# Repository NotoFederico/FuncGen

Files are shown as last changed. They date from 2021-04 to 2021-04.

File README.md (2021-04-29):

# WiFi Function and Arbitrary Waveforms Generator

---

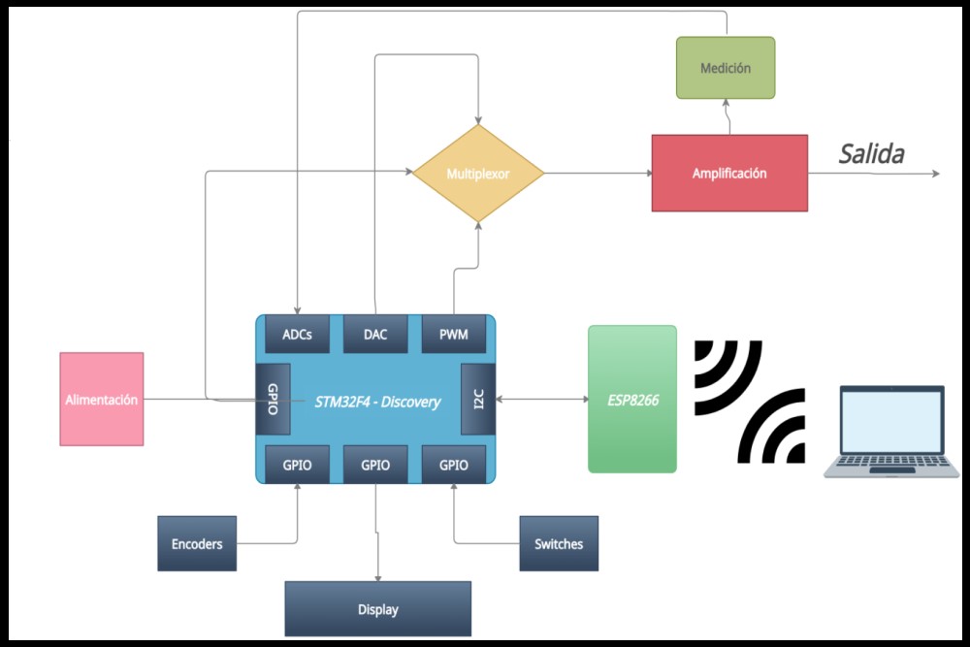
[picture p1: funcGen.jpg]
Project.Cover


---

### Download
| Latest release | Latest development build |
|---|---|
|  |  |

---

# Contents
- 1 - [Introduction](#1-introduction)
- 2 - [Paper Link](#3-paper-link)
- 3 - [Contributing](#4-contributing)
- 4 - [Licence](#5-licence)

---

# 1. Introduction

The present project aims to develop a function generator, which is exactly what its name implies: a test equipment that generates electrical signals in the form of waves that are used as stimuli for electronic measurements.

Most circuits require some type of input signal whose amplitude varies with time. The signal can be an alternating current signal (with peaks that oscillate above and below a reference) or it can vary over a range of direct current offset voltages, either positive or negative. It can be a sine wave or other analog function, a digital pulse, a binary pattern, or a purely arbitrary waveform.

The generator of signals, or functions, is the source of stimulus. Pair with a data acquisition instrument for a complete measurement solution. The two tools are connected to the input and output terminals of the device under test (DUT).

The signal generator can provide "ideal" waveforms, or it can add known and repeatable amounts and types of distortion (or errors) to the signal it delivers. This feature is one of the greatest virtues of the signal generator, as it is often impossible to create predictable distortion, exactly when and where it is needed, using only the circuit itself. The response of the device under test (DUT) in the presence of these distorted signals reveals its ability to handle voltages that fall outside the envelope of normal performance.

There are hundreds of different applications for this class of equipment, but placed in a context of electronic measurements, three categories can be divided: Verification: the designers of wireless equipment that develop new transmitting and receiving hardware must simulate baseband I&Q signals, with and without deficiencies, to verify compliance with proprietary wireless standards using arbitrary low-distortion functions.

Characterization: Newly developed digital-to-analog converters (DACs) and analog-to-digital converters (ADCs) must be thoroughly tested for their limits for linearity and distortion. Analog and digital signals are applied in phase to bring the speeds of these devices up to 1Gbps. Stress or margin test: engineers working with serial data flow architectures (commonly used in digital communication buses) need to stress their devices with deficiencies, particularly fluctuations and synchronization violations

In the project in question, known signals can be generated: such as sine, semi-diverse, square, rectangular, triangular, sawtooth and white noise and arbitrary signals, which are those signals of complex origin that do not follow a regular mathematical expression and that can be generated by the user using specialized software and subsequently sent over WiFi, thanks to a dedicated website. These signals can be chosen through a menu and their parameters, such as duty, offset and amplitude, are modifiable and will be monitored in real time on a display.

---

# 2. Paper Link

[Paper (Spanish)](https://github.com/NotoFederico/FuncGen/blob/main/FuncGen_STM32DISCO/Informe.pdf)

---

# 3. Contributing

FuncGen uses the [gitflow workflow](https://www.atlassian.com/git/tutorials/comparing-workflows#gitflow-workflow). If you are implementing a new feature or logic from the original game, please branch off and perform pull requests to ```develop```. If you are fixing a bug for the next release, please branch off and perform pull requests to the correct release branch. ```master``` only contains tagged releases, you should never branch off this.

---

# 4. Licence

FuncGen is licensed under the GNU General Public License version 3.

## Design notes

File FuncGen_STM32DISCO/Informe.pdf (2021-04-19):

## UNIVERSIDAD NACIONAL DE LA MATANZA

## Departamento de Ingeniería e Investigaciones Tecnológicas

## Ingeniería en Electrónica

# Técnicas digitales III

# Generador de funciones y ondas arbitrarias

Integrantes: | Federico A. Noto
Profesores: | Lic. Carlos Maidana
| Ing. Guillermo Buranits
| Ing. Lucas M. Guerrero
| Ing. Mauro Cipollone

2021

# ÍNDICE

UNLaM | Ingeniería Electrónica | Técnicas Digitales III
Noto Federico Antonio | 3

# 1 Descripción general

El presente proyecto tiene por objetivo desarrollar un generador de funciones, que es exactamente lo que su nombre implica: un equipo de testeo que genera señales eléctricas en forma de ondas que se utilizan como estímulo para mediciones electrónicas.

La mayoría de los circuitos requieren algún tipo de señal de entrada cuya amplitud varía con el tiempo. La señal puede ser una señal de corriente alterna (con picos que oscilan por encima y por debajo de una referencia) o puede variar en un rango de tensiones de offset de corriente continua, ya sea positivo o negativo. Puede ser una onda sinusoidal u otra función analógica, un pulso digital, un patrón binario o una forma de onda puramente arbitraria.

El generador de señales, o de funciones, es la fuente de estímulo. Se empareja con un instrumento de adquisición de datos para obtener una solución de medición completa. Las dos herramientas se conectan en los terminales de entrada y salida del dispositivo bajo prueba (DUT).

El generador de señales puede proporcionar formas de onda "ideales" o puede agregar cantidades conocidas y repetibles y tipos de distorsión (o errores) a la señal que entrega. Esta característica es una de las mayores virtudes del generador de señales, ya que a menudo es imposible crear una distorsión predecible, exactamente cuando y donde es necesario, utilizando solo el circuito en sí. La respuesta del dispositivo bajo prueba (DUT) en la presencia de estas señales distorsionadas revela su capacidad para manejar tensiones que caen fuera de la envolvente del rendimiento normal.

Existen cientos de aplicaciones diferentes para esta clase de equipos, pero colocado en un contexto de mediciones electrónicas, se pueden divisar tres categorías:

Verificación: los diseñadores de equipos inalámbricos que desarrollan nuevo hardware de transmisión y recepción deben simular señales I&Q de banda base, con y sin deficiencias, para verificar la conformidad con los estándares inalámbricos patentados y para ello se usan funciones arbitrarias de baja distorsión.

Caracterización: los convertidores digital a analógico (DAC) y los convertidores analógico a digital (ADC) recientemente desarrollados deben probarse exhaustivamente para determinar sus límites de linealidad y distorsión. Se aplican señales analógicas y digitales en fase para llevar las velocidades de estos dispositivos hasta 1Gbps.

Test de estrés o margen: los ingenieros que trabajan con arquitecturas de flujo de datos en serie (comúnmente utilizadas en buses de comunicaciones digitales) necesitan estresar sus dispositivos con deficiencias, particularmente fluctuaciones y violaciones de sincronización

En el proyecto en cuestión, se podrán generar señales conocidas: como seno, semiverseno, cuadrada, rectangular, triangular, diente de sierra y ruido blanco y señales arbitrarias, que son aquellas señales de origen complejo que no siguen una expresión matemática regular y que podrán ser generadas por el usuario mediante un software especializado y posteriormente enviadas a través de WiFi, gracias a un sitio web dedicado. Dichas señales podrán ser elegidas a través de un menú y sus parámetros, tales como duty, offset y amplitud, son modificables y serán monitoreados en tiempo real en un display.

# 2 Introducción teórica

## 2.1 Forma de onda

El término "onda" se puede definir como un patrón de valores cuantitativos variables que se repite durante algún intervalo de tiempo. Las ondas son comunes en la naturaleza: ondas sonoras, ondas cerebrales, ondas oceánicas, ondas de luz, ondas de tensión y muchas más. Todos son fenómenos que se repiten periódicamente. Los generadores de señales generalmente se preocupan por producir ondas eléctricas (típicamente de voltaje) que se repiten de manera controlable.

Cada repetición completa de una onda se conoce como un "ciclo". Una forma de onda es una representación gráfica de la actividad de la onda: su variación en el tiempo. Una forma de onda de tensión es un gráfico cartesiano clásico con tiempo en el eje horizontal y tensión en el eje vertical.

## 2.1.1 Amplitud

Una medida de la “fuerza” de la tensión de la forma de onda. La amplitud cambia constantemente en una señal de corriente alterna. Los generadores de señales le permiten establecer un rango de tensión, por ejemplo, —5V a +5V. Esto producirá una señal que fluctuará entre los dos valores de tensión, y la tasa de cambio dependerá tanto de la forma de onda como de la frecuencia.

## 2.1.2 Frecuencia

La velocidad a la que ocurren los ciclos completos de formas de onda. La frecuencia se mide en Hertz (Hz), antes conocida como ciclos por segundo. La frecuencia está inversamente relacionada con el período de la forma de onda, que es una medida de la distancia entre dos picos similares en ondas adyacentes. Las frecuencias más altas tienen períodos más cortos y viceversa.

## 2.1.3 Fase

En teoría, es la ubicación de un ciclo de una forma de onda en relación con un punto de 0 grados. En la práctica, la fase es la ubicación temporal de un ciclo en relación con una forma de onda de referencia o de un punto en el tiempo.

## 2.1.4 Tiempo de subida y de bajada

Más conocido como rise time y fall time respectivamente. Son medidas del tiempo que tarda el flanco de la señal en realizar una transición de un estado a otro. En los circuitos digitales modernos, estos valores suelen estar en el rango de nanosegundos o menor.

Los tiempos de subida y bajada se miden entre los puntos del 10% y el 90% de los niveles de tensión estático antes y después de la transición (a veces se utilizan puntos del 20% y del 80% como alternativas).

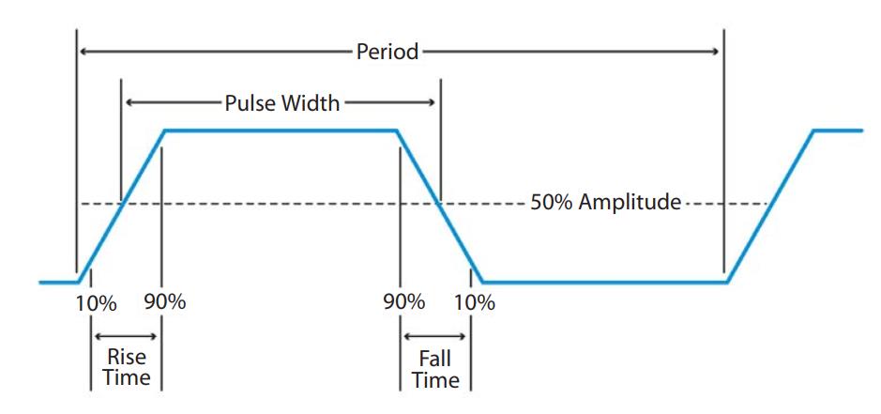
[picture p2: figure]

Figura 1 - <Características básicas de un pulso>

## 2.1.5 Ancho de pulso

El ancho de pulso es el tiempo que transcurre entre los flancos inicial y final de un pulso. Para tener en cuenta que el término "inicial" se aplica a los flancos positivos o negativos, al igual que el término "final". En otras palabras, estos términos denotan el orden en que ocurren los eventos durante un ciclo dado. La polaridad de un pulso no afecta su estado como flanco inicial o final.

Otro término, "ciclo de trabajo" (duty cycle), se usa para describir los intervalos de tiempo alto y bajo (encendido / apagado) de un pulso. Por ejemplo, un actuador que descansa 3 segundos luego de 1 segundo de actividad representa un duty cycle del 25% en un periodo de 4 segundos.

## 2.1.6 Offset

No siempre las señales tienen sus variaciones de amplitud centradas en una referencia de tierra (0V). La tensión de "offset" es la tensión entre la tierra del circuito y el centro de la amplitud de la señal. La tensión de offset expresa la componente de corriente continua de una señal que contiene valores tanto de corriente alterna como de corriente continua.

Figura 2 - <Tensión de offset sobre una señal alterna>

## 2.2 Conversor digital a analógico (DAC)

Un convertidor digital a analógico (DAC) es un dispositivo que convierte un código digital en una señal analógica. Los convertidores digitales a analógico son la interfaz entre el mundo digital abstracto y la vida real.

En la siguiente imagen puede apreciarse que N palabras digitales de n bits son aplicadas a la entrada del DAC, que luego se convierten en una señal analógica a la frecuencia de muestreo (Fs) aplicada al clock del DAC.

Figura 3 - <Características básicas del DAC>

## 2.2.1 Profundidad de memoria (longitud de registro)

La profundidad de la memoria, o la longitud del registro, está íntimamente ligada con la frecuencia del clock. La profundidad de la memoria determina el número máximo de muestras que se pueden almacenar. Cada punto de muestra de forma de onda ocupa una ubicación de memoria. Cada ubicación equivale al valor de un intervalo de muestra de tiempo a la frecuencia del clock actual. Si el clock funciona a 100 MHz, por ejemplo, las muestras almacenadas están separadas por 10 ns.

## 2.2.2 Frecuencia de muestreo

La frecuencia de muestreo, generalmente especificada en términos de MS/s o GS/s, denota el clock máximo o la frecuencia de muestreo a la que puede funcionar el instrumento. La frecuencia de muestreo afecta la frecuencia y fidelidad de la señal de salida. El teorema de muestreo de Nyquist establece que la frecuencia de muestre, debe ser más del doble que la componente de frecuencia espectral más alta de la señal generada, para garantizar una reproducción precisa de la señal. Para generar una señal de onda sinusoidal de 1 MHz, por ejemplo, es necesario producir puntos de muestra a una frecuencia de más de 2 MS/s.

## 2.2.3 Resolución Vertical

La resolución vertical se refiere al tamaño de la palabra binaria en bits del DAC del instrumento. Más bits equivalen a una resolución más alta. La resolución vertical del DAC define la precisión de amplitud

(tensión) y la distorsión de la forma de onda reproducida. Un DAC con resolución inadecuada contribuye a errores de cuantificación, provocando una generación de forma de onda imperfecta.

## 2.2.4 Resolución Horizontal

La resolución horizontal expresa el incremento de tiempo más pequeño que se puede utilizar para crear formas de onda. Normalmente, esta cifra es simplemente el resultado del cálculo:

T = 1 / F donde T es la resolución de tiempo en segundos y F es la frecuencia de muestreo.

## 2.3 Modulación por ancho de pulso (PWM)

La modulación por ancho de pulsos (PWM, de sus siglas en inglés) de una señal o fuente de energía es una técnica en la que se modifica el ciclo útil de una señal periódica (pudiendo ser una senoidal o una cuadrada), para transmitir información a través de un canal de comunicaciones o para controlar la cantidad de energía que se envía a una carga.

El ciclo de trabajo de una señal periódica es el ancho relativo de su parte positiva en relación con el período. Expresado matemáticamente:

Ciclo útil =

Tiempo de la señal en esta alto Tiempo total del período

En la actualidad existen muchos circuitos integrados en los que se implementa la modulación PWM, además de otros muy particulares para lograr circuitos funcionales que puedan controlar fuentes conmutadas, controles de motores, controles de elementos termoeléctricos, etc.

# 3 Descripción técnica del proyecto

## 3.1 Hardware

Las prestaciones del equipo son las siguientes:

- Formas de onda: senoidal, semiverseno, diente de sierra, triangular, cuadrada, rectangular, ruido blanco y ondas arbitrarias.
- Para la forma de onda rectangular se puede elegir un ciclo de trabajo del 1% al 99% con una resolución de 8 bits.
- Rango de frecuencia: 1Hz a 20kHz
- Resolución de frecuencia: +/- 1Hz para frecuencias bajas; +/- 100Hz para frecuencias altas
- Amplitud: 0Vpp a 20Vpp
- Resolución de amplitud: 200mV
- Offset: +/- 5V
- Resolución del offset: 20mV
- Cantidad de muestras: 4000

## 3.1.1 Diagrama en bloques

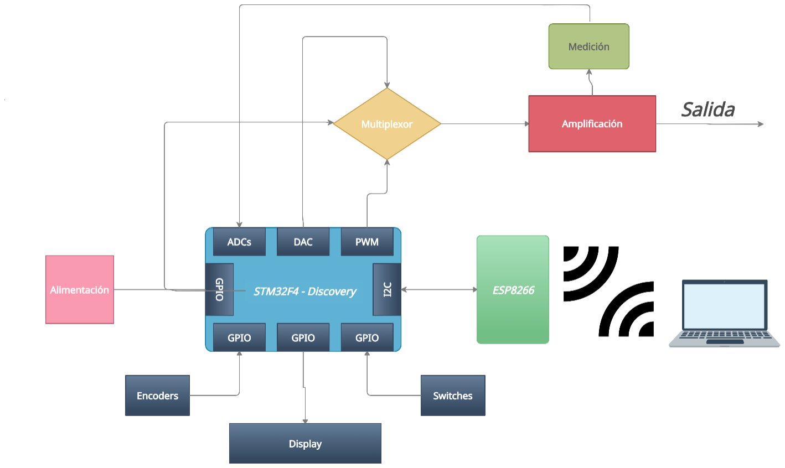
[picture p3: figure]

Figura 4 - <Diagrama en bloques del proyecto>

A partir de una fuente de 24V se alimenta al equipo, donde se derivan los niveles de tensión necesarios para cada bloque. Los diferentes periféricos de los que se hablará a continuación forman parte del kit de desarrollo STM32F4 – Discovery.

Dentro de los GPIO (perifericos generales de entrada/salida) de entrada, nos encontramos con encoders rotativos y switches que nos permiten interactuar con un simple menú que nos permiten elegir distintas pantallas, elegir formas de onda y seleccionar valores de magnitudes unidad por unidad. El menú puede visualizarse en un display de 20x4 caracteres (periferico general de salida).

La forma de onda elegida puede ser generada a través del DAC (conversor digital a analógico) para formas de onda clásicas como seno, semiverseno, triangular, diente de sierra y ruido blanco y otras especiales como las ondas arbitrarias. Luego con el PWM puede generarse formas de onda tal como cuadrada y rectangular. Tanto la salida del DAC como PWM están conectadas a un multiplexor que selecciona solo una sola señal, dicha selección está controlada por un GPIO proveniente del microcontrolador. Posteriormente, la señal elegida es amplificada y acondicionada para ser leída por un ADC, dichas magnitudes pueden ser consultadas en cualquier momento en el display.

El bloque perteneciente al ESP8266, levanta un servidor que permite la gestión de ondas arbitrarias a través de WiFi y se comunica con el microcontrolador utilizando el protocolo I2C. Las ondas arbitrarias deberán ser generadas previamente con un software especializado para dicha actividad y luego cargadas al sitio web en LAN para que el usuario gestione las formas de onda cargadas en el servidor.

## 3.1.2 Esquemático

3.1.2.1 Bornera de fuente de alimentación

Una simple bornera de dos pines alimenta a todo el circuito con una fuente de 24V.

3.1.2.2 Alimentación principal +/-12V

La fuente de 24V es dividida en +/-12V con una tierra virtual.

Figura 5 - <Esquemático de alimentación +/-12V>

3.1.2.3 Alimentación principal +5V y 3.3V

Las tensiones de alimentación de +5 y +3.3V se logran con circuitos integrados de reguladores, LM7805 y LM7833 respectivamente. La tensión de entrada en cada caso es de +12V y se colocan capacitores tanto en la entrada como en la salida tal como especifica la hoja de datos. En la entrada un capacitor electrolítico de 0.22uF con referencia a GND por si el filtro de fuente se encuentra lejos del regulador y en la salida un capacitor cerámico de 100nF con referencia a GND para mayor estabilidad.

3.1.2.4 STM32F4-Discovery Kit

Se utiliza a la placa de desarrollo como eje central de este proyecto. Se encarga de generar las formas de onda, aplica el algoritmo matemático necesario para la obtención de cada señal y también el algoritmo para determinar la cantidad de muestras y la frecuencia de muestreo, tanto para las formas de onda que correspondan al DAC o al PWM. También es el responsable de enviar las cadenas de caracteres que se desean imprimir en el display (enable (E), reset (RS), DB4-DB7), de colocar el valor lógico correspondiente en ChSelect para conmutar la salida del multiplexor, de interpretar la posición de los dos encoders (CLKx, DTx y SWx), de atender las interrupciones de hardware de los dos pulsadores (SW3 y SW4), de recibir la información correspondiente de las ondas arbitrarias mediante el protocolo I2C (SDA y SCL) que actua como esclavo y de interpretar los valores de tensión recibidos a las entradas de los tres ADCs: tensión de salida amplificada de la señal (AmpDac), tensión de salida del offset (OffsetDac) y signo del offset (PolarityDac). Es alimentada con +5V provenientes de una conexión USB.

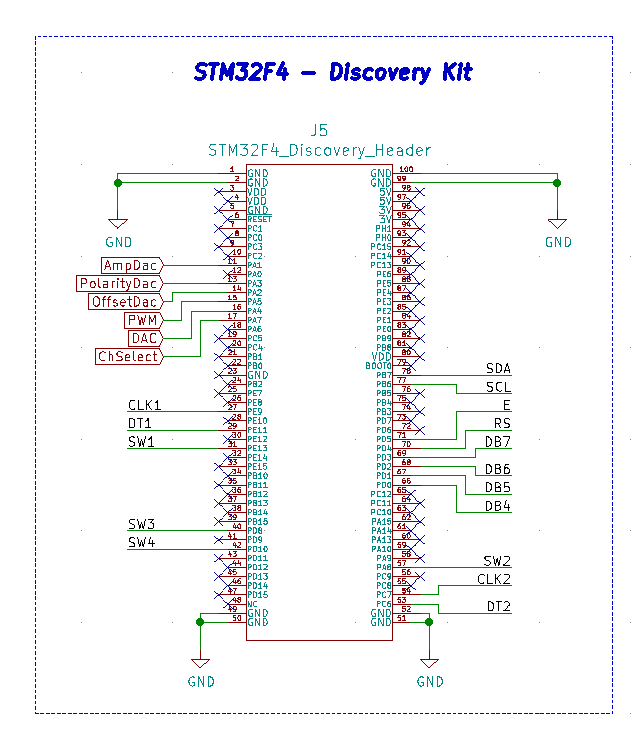
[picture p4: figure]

Figura 6 - <Esquemático del kit STM32F4 - Discovery>

3.1.2.5 ESP8266 – NODEMCU – 1.0

El ESP8266 NODEMCU es un kit de desarrollo que ofrece una solución completa con conectividad WiFi, lo que le permite alojar la aplicación o servir como puente entre internet y un microcontrolador.

Se eligió este kit por su practicidad en cuanto aspectos de alimentación vía puerto micro USB, facilidad de programación, tamaño de memoria y la posibilidad de expansión del proyecto, dado que hay muchos periféricos aún disponibles.

Esta versión en particular cuenta con 30 pines disponibles para el usuario de los cuales nos son de interés los pines de +3.3V de alimentación y los de comunicación I2C (SCL y SDA), con los cuales el ESP8266 establece una comunicación como maestro, con el microcontrolador. El fin de este dispositivo en el proyecto es levantar un servidor (WebSocket) que aloja una página web (HTML, CSS, JS) en la red de área local (utilizando DHCP) para listar, subir, enviar (I2C) y borrar archivos que almacenen conjuntos de muestras de formas de ondas arbitrarias (.csv).

3.1.2.6 Display 2004A

Es un display de 20x4 caracteres, que se alimenta con +5V y lleva un capacitor de 100nF como protección contra sobretensiones. El ánodo se conecta a +5V y el cátodo a GND (para encender el display). Luego el brillo de los caracteres se regula con un trimpot de 10k conectado al pin VO del display, como recomienda la hoja de datos del fabricante. Se conecta de tal manera para que funcione como divisor resistivo, con la alimentación en los extremos y el punto medio conectado a VO. Luego los pines de información solo se utilizan de DB4-DB7 y los de control como Reset (RS), Enable (E) y Read/Write(RW) a GND para realizar escrituras.

La función del display en el proyecto es mostrar las diferentes “pantallas” del menú, para una fácil interacción entre el usuario y el equipo. Se eligió por su practicidad, bajo precio y experiencia previa con esta clase de display.

3.1.2.7 Switches

Dos simples switches conectados entre GND y los GPIO del microcontrolador, funcionan como interrupciones externas de hardware para desplazarse por las distintas pantallas del menú, de arriba hacia abajo y viceversa.

3.1.2.8 Encoders

Dos encoders rotativos KY-040 se utilizan para que el usuario interactúe en cada “pantalla” del menú, permitiendo seleccionar unidades y números referentes a magnitudes tales como frecuencia y duty cycle y seleccionar la forma de onda de salida. Uno de los encoders se encarga siempre de los desplazamientos en el eje horizontal y el otro de los encoders se encarga siempre de los desplazamientos en el eje vertical.

Cada encoder tiene 5 pines, DT, SW, CLK, +5V y GND. Los primeros tres son conectados al microcontrolador principal y controlados por un timer en modo encoder y los otros dos pines a alimentación. Se eligieron pensando en una experiencia de usuario diferente a utilizar un teclado matricial y porque el microcontrolador ofrece un modo de configuración idóneo para este tipo de periférico.

3.1.2.9 Selección de señal
En este apartado se logra que con un estado o alto o bajo proveniente de ChSelect pueda elegirse que la señal del DAC o del PWM pase a una instancia de amplificación. Para ello se utilizó un integrado multiplexor/demultiplexor, el CD4051. Este posee, ocho entradas, una salida, tres pines de control y un pin de habilitación. Este integrado es alimentado con +5V y lleva un capacitor de 100nF como protección contra sobretensiones. De las ocho entradas utilizamos solo dos, cableadas a DAC y PWM, X0 y X1 respectivamente. Con solo el pin de control A se logra controlar la selección entre ambas entradas (X0 y X1), mientras que los pines B, C y INHIBIT permanecen conectados a GND (ver tabla de verdad).

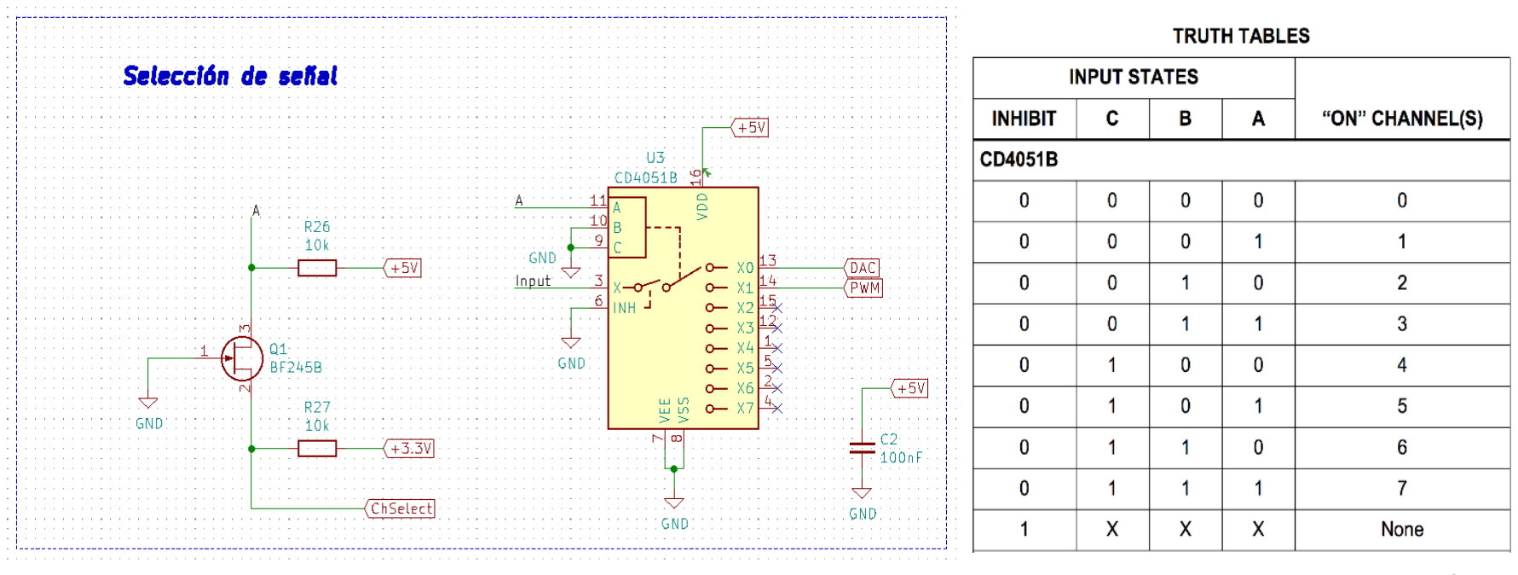
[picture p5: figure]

Figura 7 - <Tabla de verdad de selección de canal del CD4051>

Según la hoja de datos, con una alimentación de +5V, se necesita una tensión de hasta 1.5V para que el integrado interprete un “0” lógico y más de 3.5V para un “1” lógico. Dado que la tensión de salida de los pines del microcontrolador principal excursionan entre 0V y 3.3V necesitamos shiftear o adaptar los niveles de tensión. Como solución a este problema se implementó un circuito level shifter con un JFET BF245B. El gate del mismo está conectado a GND, el source a ChSelect y el drain a la salida del pin del control A y a +5V a través de un resistor de 10kΩ. Cuando ChSelect es 0V la tensión entre gate y source es también 0V, por lo tanto, la VGS del transistor es 0V, entonces no fluye corriente a través del drain y la tensión en A, es de alrededor de 0V. Si ahora en ChSelect se aplica una tensión de 3.3V, la VGS será de 3.3V y logramos que la tensión en el drain y por lo tanto en A, sea de 5V.

Figura 8 - <Esquemático de selección de señal>

3.1.2.10 Amplificación y acondicionamiento de la señal de amplificación

Posterior a la selección de la señal, la etapa que siguiente es la de amplificación. Primeramente, se desacopla de su componente de continua, dado que la señal que genera el DAC tiene una tensión mínima de 0V y una máxima de 2.92V (limitada para no deformar la forma de onda), lo que implicaría que ya tiene un offset de 1.46V aproximadamente. De esta manera, montamos el centro de la señal sobre 0V. Se utilizan dos capacitores en paralelo de 133uF en total (100uF + 33uF). Realizamos esta configuración con valores experimentales ya que en la práctica se observó que la señal de salida estaba derivándose para bajas frecuencias (< 20Hz), dado que el capacitor de desacople seguido por un amplificador inversor toma la topología de un amplificador derivador. Según una simulación en LTSpice, se comprobó que para valores de R10 = 33kΩ y R7 = 5.6kΩ, a pesar de obtener una ganancia cercana a la deseada (G = -R10/R7) el efecto del derivador actuaba para frecuencias menores a 20 Hz.

Figura 9 - <Respuesta en frecuencia con R10 = 33kΩ y R7 = 5.6kΩ >

Del gráfico observamos que f−3db = ~3 Hz y f0db = 36mHz

Como solución se elevaron los valores de R10 y R7 para que el efecto de derivación no ocurra en el rango de frecuencias de este generador. Los nuevos valores de resistores propuestos son R10 = 680kΩ y R7 = 100kΩ.

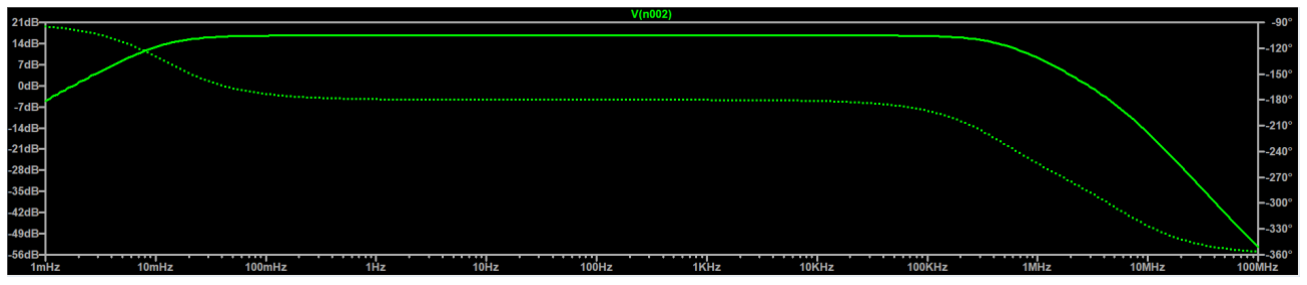
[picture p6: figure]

Figura 10 - <Respuesta en frecuencia con R10 = 680kΩ y R7 = 100kΩ.>

Del gráfico observamos que f−3db = ~160 mHz y f0db = 1. 76mHz

La ganancia es constante entre 1Hz y 20kHz. El efecto del derivador ocurre entre 1.76mHz y 160mHz. También ocurre que la señal es integrada para señales a partir de 1MHz.

Una vez desacoplada la señal la señal es amplificada con un amplificador operacional (TL072, doble AOP de propósito general) en configuración inversora y alimentado con ±12V, que se rige por la siguiente ecuación:

Vi ∗

680kΩ
100kΩ

= Vo → Vi ∗ 6.8 = 2.92V ∗ 6.8 = 19.85Vpp

Cumpliendo con el requerimiento de entregar alrededor de 20Vpp. Ahora bien, lo que hemos conseguido hasta aquí es que la señal alcance su valor máximo, aunque sin regulación. Entonces utilizamos un potenciómetro de 100kΩ para atenuar la señal hasta un valor mínimo de 19.85Vpp ∗

1Ω
100kΩ

= 0.19mVpp y un máximo de 20Vpp. Finalmente se emplea el otro AOP de la pastilla como buffer y entregar una señal con muy baja impedancia de salida.

Un detalle no menor, es que el potenciómetro empleado es un potenciómetro doble, si se observa en el esquemático se observa que los pines del segundo potenciómetro están conectados a GND y +3.3V y el pin AmpDac que se cablea al ADC1 del microcontrolador principal. Es decir que por la salida AmpDac, la tensión puede pivotear entre 0V y 3.3V, comportándose como un acondicionador de la señal amplificada, mientras que la tensión en el primer potenciómetro excursiona entra 0.20mVpp y 20Vpp. Esto es posible de lograr dado que ambos potenciómetros están ligados mecánicamente y no eléctricamente.

Figura 11 - <Esquemático del amplificador de la señal>

3.1.2.11 Generación de la tensión de offset

Para generar un valor de tensión continua (offset) que pudiese excursionar entre -5V y +5V y limitar la corriente en 1mA se planteó el circuito de la figura. Donde se utilizan, en un principio, dos diodos Zener y tres resistores conectados en sus extremos a -12V y +12V. La ecuación matemática es la siguiente:

−12V – (R2 + RV1 + R4) ∗ I + 12V = 0V

Supongamos que limitamos la corriente I a 1mA. Si despejamos la suma de R2, RV1 y R4, obtendríamos que se necesitan 24kΩ en total. Podríamos entonces elegir dos resistores de 7kΩ y uno de 10kΩ, pues la suma es 24kΩ. Ahora bien, no existen resistores de 7kΩ y lo más próximo a ello es poner en paralelo dos resistores, uno de 8.2kΩ y otro de 47kΩ, resultando en una resistencia equivalente de 7kΩ. y un potenciómetro de 10kΩ para lograr una variación entre -5V y +5V.

De aquí nos encontramos con dos problemas. El primero es que la tensión en los zeners nunca llegaba a ±5V y el segundo problema, que girar la perilla del potenciómetro provocaba saltos de tensión aleatorios.

Si observamos el primer problema, tendríamos que analizar que ocurre con el potencial en R2;RV1 y R4;RV1. Tomamos el nodo R2;RV1, el potencial allí es:

−12V − 7kΩ ∗ −1mA = −5V

Análogamente para R4;RV1, la tensión en el nodo será de +5V. A primera vista se creía que eso era lo que se buscaba, pero al mismo tiempo ese era el problema. Los pares de zeners de 5.1V y 5.6V probados no estaban operando dado que la tensión estaba por debajo del umbral de su funcionamiento (10V de diferencia de potencial en el potenciómetro). Como solución se reemplazó el potenciómetro de 10kΩ por otro de 100kΩ. Si volvemos a plantear las ecuaciones anteriores:

-12V – (7kΩ + 100kΩ + 7kΩ)*I + 12V = 0V

Despejando I, obtenemos que I = 210uA. Luego comprobamos el potencial en R2;RV1,

−12V − 7kΩ ∗ −210mA = −10.53V

Es decir que ahora sobre el potenciómetro hay una diferencia de potencial de alrededor de 21V y los zeners pueden actuar. En la práctica se midieron ±5.20V con diodos zeners de 5.6V. El segundo problema fue solucionado reemplazando el potenciómetro de 100kΩ por un trimpot de 100kΩ.

Por último, se empleó un amplificador operacional TL072 como buffer por cuestiones de impedancia.

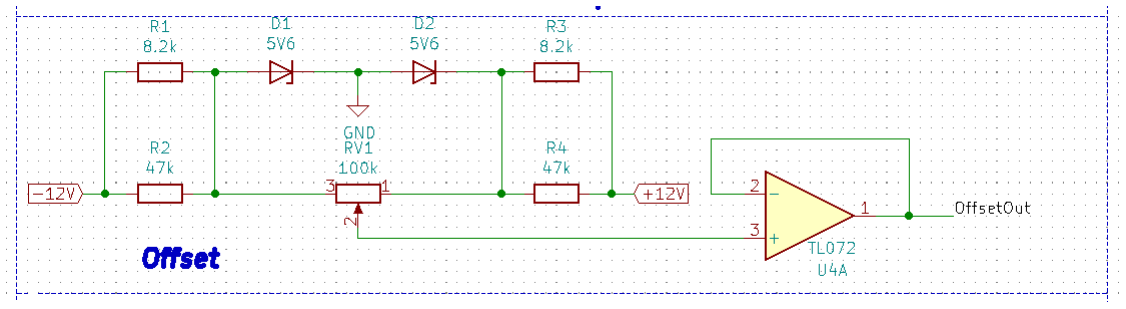
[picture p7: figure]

Figura 12 - <Esquemático del generador de offset>

3.1.2.12 Suma de la señal amplificada y la tensión de offset

La señal de offset y la señal amplificada son sumadas en un amplificador operacional (TL072, alimentado con ±12V) en configuración sumador inversor con ganancia unitaria. Si analizamos utilizando el principio de superposición, comprobaremos que la ganancia es unitaria.

Por ej.: si pasivamos la entrada OffsetOut nos queda que:

- AmpOut − R5 ∗ I = 0 ➔ I =

AmpOut
R5
- −R11 ∗ I = Output ➔ − R11 ∗

AmpOut
R5

= Output
- Y como R11 y R5 son iguales (10kΩ) ➔ AmpOut = −Output

Análogamente OffsetOut = −Output, entonces, AmpOut + OffsetOut = −Output

Todos los resistores son de 10kΩ por cuestiones de estabilización.

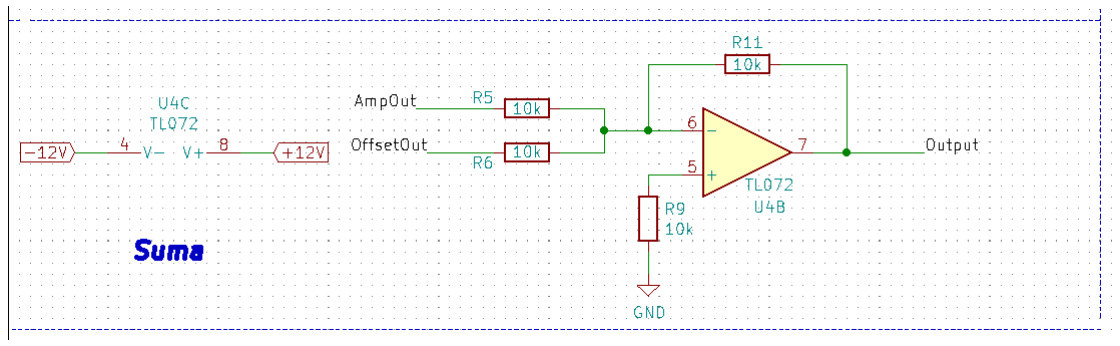
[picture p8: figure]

Figura 13 - <Esquemático de la suma de señal CC y AC>

3.1.2.13 Acondicionador de señal de la señal de offset

Si se desea medir el valor de la tensión de offset con un microcontrolador el problema más aparente que nos encontramos son los niveles de tensión. Ya que, a una entrada, y particularmente, a una entrada configurada como ADC, no es posible enviarle valores negativos o mayores a los de su tensión de referencia sin dañarlo. Por ello, se planteó la siguiente red, que nuevamente utiliza amplificadores operacionales TL072, alimentados con ±12V. Esta red cumple la función de traducir valores de 0V a 3V para el rango de 0V a -5V y de la misma manera, de 0V a 3V para el rango de 0V a +5V de offset.

Figura 14 - <Esquemático del acondicionador de la señal de offset>

Este circuito debe ser analizado en dos partes. Una cuando la tensión OffsetOut > 0 y otra cuando es <0.

3.1.2.13.1 Caso I – OffsetOut positivo

- D4 resulta polarizado en inversa, no es considerado en el análisis
1. OffsetOut – R13 ∗ IR1 = 0 → IR1 =

OffsetOut
R13

2. IR1 = IR18 = I1
3. Vo′ = VR18;R21
4. −R18 ∗ I1 = Vo

′ =→ −R18 ∗

OffsetOut
R13

= Vo

′
; (1), (2) y (3) en (4)
5. IR21 = I2
6. IR23,25 = I2
7. Vo

′
R21

= I2 ; (3), (5) en (6)

8. −(R23 + R25) ∗

Vo’
R21

= OffsetDac ; (7) en (8)

9. (R23 + R25) ∗ R18 ∗

OffsetOut
R13∗R21

= OffsetDac ; (4) en (8)

De la expresión (9) podemos determinar que ante un valor positivo de OffsetOut el circuito se comporta como un amplificador no inversor. Si fijamos R18, R13 y R21 en 10kΩ y despejamos R23+R25 tomando como OffsetOut = +5V y OffsetDac = +3V, obtenemos que R23+R25 = 6kΩ = 3.3kΩ + 2.7kΩ respectivamente.

3.1.2.13.2 Caso II – OffsetOut negativo

- D3 resulta polarizado en inversa, no es considerado en el análisis
1. OffsetOut + R13 ∗ IR1 = 0 → IR1 = −

OffsetOut
R13
2. IR16,19 = IR13 + IR18,21
3. Vx = VR18,R21,D4
4. (R18 + R21) ∗ IR18,21 = Vx
5. Vx − IR18,21 ∗ (R23 + R25) = OffsetDac
6. (R16 + R19) ∗ IR16,19 = −(R18 + R21) ∗ IR18,21
7. (R16 + R19) ∗ (−

OffsetOut
R13

+ IR18,21 ) = − (R18 + R21) ∗ IR18,21

- (R16 + R19) ∗ IR18,21 −

OffsetOut
R13

∗ (R16 + R19) = −(R18 + R21) ∗ IR18,21

- −

(R16+R19)
R13

∗ OffsetOut = −IR18,21 ∗ (R16 + R19 + R18 + R21)

- OffsetOut ∗

(R16+R19)
R13∗(R16+R19+R18+R21)

= IR18,21

8. −(R18 + R21) ∗ OffsetOut ∗

(R16+R19)
R13∗(R16+R19+R18+R21)

− OffsetOut ∗

(R16+R19)
R13∗(R16+R19+R18+R21)

∗
(R23 + R25) = OffsetDac
9. −OffsetOut ∗

(R16+R19)
R13∗(R16+R19+R18+R21)

∗ (R18 + R21 + R23 + R25) = OffsetDac

De la expresión (9) podemos determinar que ante un valor negativo de OffsetOut el circuito se comporta como un amplificador inversor. Ya sabíamos que:

- R13 = R18 = R21 = 10kΩ
- R23 = 3.3kΩ
- R25 = 2.7kΩ

De aquí nos queda de incógnita R16 y R19, si los despejamos de (9) tomando a OffsetOut = -5V y a OffsetDac = +3V. Obtenemos que R16 + R19 = 6kΩ = 3.3kΩ + 2.7kΩ respectivamente.

De esta manera nos aseguramos en ambos casos que la tensión de salida sea positiva y acotada en el rango de 0V a 3V cableada al DAC2 del microcontrolador

3.1.2.14 Signo de la señal de offset

Anteriormente obtuvimos la magnitud del offset escalada a una tensión compatible con el microcontrolador. El detalle que ha sido pasado por alto es el signo de tal magnitud, por ello, el siguiente circuito cumple el rol de entregar valores positivos de 0V a 1.5V para una tensión de entrada de 0V a -5V y de 1.5V a 3V para una tensión de entrada de 0V a +5V.

Se utilizan dos amplificadores operacionales de un integrado TL072, alimentados con ±12V. El primer operacional se comporta como un sumador inversor y el segundo como un inversor de ganancia unitaria.

Aplicando el principio de superposición:

Para la entrada: OffsetOut

OffsetOut − R14 ∗ I = 0 → I =

OffsetOut
R14

−R20 ∗ I = VR20,R22 = Vx

Vx = −R20 ∗

OffsetOut
R14

Para la entrada: +5V

+5V – R14 ∗ I = 0 → I =

+5V
R15

−R20 ∗ I = VR20,R22 = Vx

Vx = −R20 ∗

+5V
R15

La suma de ambas Vx resulta Vx = −R20 ∗ (

+5V
R15

+

OffsetOut
R14

)

Como habíamos aclarado previamente, el segundo amplificador invierte la señal y tiene ganancia unitaria, entonces, la tensión PolarityDac resulta:

PolarityDac = R20 ∗ [

+5V
R15 +

OffsetOut
R14 ]

Si fijamos R20 = 10kΩ, debemos hallar R14 y R15 de tal manera que cumpla con nuestros requisitos. Plantearemos el siguiente sistema de ecuaciones:

1.5V = 10kΩ ∗ [

+5V
R15 +

−5
R14 ]

3V = 10kΩ ∗ [

+5V
R15 +

+5
R14 ]

Despejando y sustituyendo, obtenemos que los valores de R14 = R15 = 33kΩ

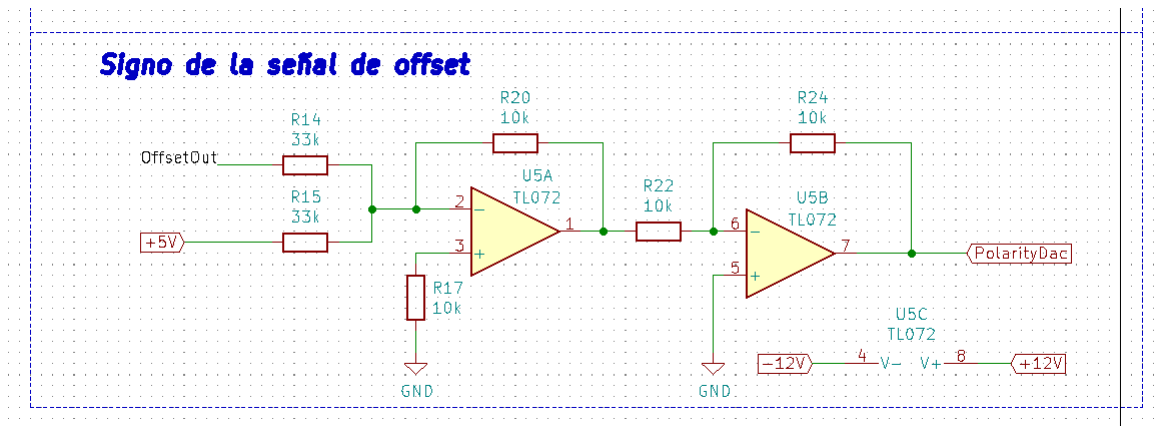
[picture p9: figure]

Figura 15 - <Esquemático de la obtención del signo de la señal de offset>

3.1.2.15 Bornera de alimentación y pines de entrada y salida

Se emplea una bornera de 5 pines para los distintos valores de alimentación, +12V, -12V, +5V, 3.3V y GND.

Una pinera de tres pines para las salidas del microcontrolador: DAC, PWM y ChSelect.

Una pinera de tres pines para las salidas de la sección de electrónica analógica: AmpDac, OffsetDac y PolarityDac.

Una pinera de dos pines para la salida de amplificación: Output, GND.

## 3.1.3 Circuito impreso

En esta sección se pueden hacer los comentarios que se consideren necesarios sobre el diseño del circuito impreso. La imagen de este completo se debe colocar en el anexo (no en el medio del desarrollo de esta sección).

Al momento de la entrega de este informe hay presentes tres circuitos impresos:

PCB de alimentación principal que involucra a los siguientes bloques:

- Bornera de fuente de alimentación,
- La alimentación principal de +/- 12V, +5V, 3.3V y GND virtual.

PCB de electrónica analógica que involucra a los siguientes bloques:

- Selección de la forma de onda
- Amplificación de la forma de onda
- Generación de la señal de offset
- La suma de la forma de onda y la señal de offset
- El acondicionamiento de la señal amplificada, la señal de offset y el signo de la señal de offset.
- Bornes de alimentación

PCB de interacción con que involucra a los siguientes bloques:

- Kit de desarrollo STM32F4- Discovery
- Módulo WiFi: ESP8266 NodeMCU 1.0
- Los dos encoders rotativos
- Los dos switchs
- El display
- Bornes de alimentación

## 3.1.4 Fotos

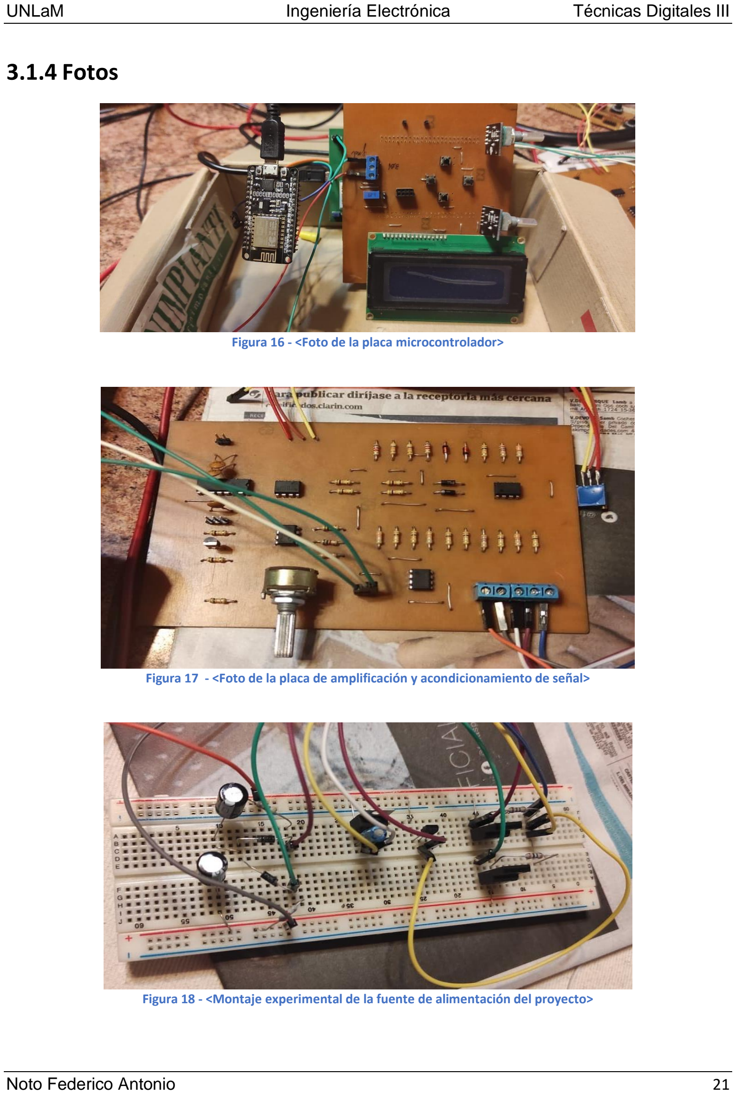
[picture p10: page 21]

Figura 16 - <Foto de la placa microcontrolador>

Figura 17 - <Foto de la placa de amplificación y acondicionamiento de señal>

Figura 18 - <Montaje experimental de la fuente de alimentación del proyecto>

## 3.2 Software

## 3.2.1 Enumeración de rutinas

- Rutina “main”: < Bucle principal >
- Subrutina “HAL_Init” :<Reset de periféricos, inicialización de la interfasz Flash y del Systick>
- Subrutina ”SystemClock_Config” :<Configura el clock del sistema>
- Subrutina “MX_GPIO_Init” : <Inicializa los GPIO>
- Subrutina “MX_DMA_Init” : <Inicializa el DMA>
- Subrutina “MX_I2C1_Init” : <Inicializa el I2C>
- Subrutina “MX_ADC3_Init” : <Inicializa el ADC3>
- Subrutina “MX_DAC_Init” : < Inicializa el DAC>
- Subrutina “MX_TIM1_Init” : < Inicializa el timer 1, utilizado en modo encoder>
- Subrutina “MX_TIM2_Init” : < Inicializa el timer 2, utilizado como base de tiempo para el PWM>
- Subrutina “MX_TIM3_Init” : < Inicializa el timer 3 como base de tiempo en us para las rutinas del display>
- Subrutina “MX_TIM6_Init” : < Inicializa el timer 6, utilizado como base de tiempo para el DAC>
- Subrutina “MX_TIM8_Init” : < Inicializa el timer 8, utilizado en modo encoder>
- Subrutina “MX_ADC2_Init” : <Inicializa el ADC2>
- Subrutina “MX_ADC3_Init” : <Inicializa el ADC3>
- Subrutina “HAL_TIM_Base_Start” :<Arranca la base de tiempo del timer>
- Subrutina “HAL_TIM_PWM_Start” :<Arranca el PWM en la configuración dada>
- Subrutina “HAL_TIM_Encoder_Start ” :<Arranca el timer en modo encoder>
- Subrutina “HAL_GPIO_WritePin ”:<Escribe el estado del pin>
- Subrutina “welcome” :<Imprime un mensaje de bienvenida>
- Subrutina “button_check” :<Comprueba si un pulsador fue pulsado y que acción realizar>
- Subrutina ”menu” :<Ejecuta el menú>
- Rutina “menú” : <Determina la pantalla a mostrar>
- Subrutuna “HAL_ADC_Stop_DMA”:<Detiene el ADC DMA>
- Subrutina “selector” :<Determina la dirección de desplazamiento en el menú>
- Subrutina “cls_lcd” : <Limpia la pantalla del display>
- Subrutina “print_shifted” : <Imprime un string en una línea y posición particular en el display>
- Subrutina “main_screen” : <Muestra la pantalla principal>
- Subrutina “waveforms_menu”: <Menú de selección de la forma de onda a generar>
- Subrutina “frequency_menu ” :<Menú de selección de la frecuencia>
- Subrutina “arbwave_menu” :<Menú de obtención de la forma de onda arbitraria>
- Subrutina “dutycycle_menu” :<Menú de selección del duty cycle>
- Rutina “main_screen” : <Imprime en el display todos los parámetros de la onda seleccionada>
- Subrutina “print_labels” :<Imprime los títulos>

- Subrutina “print_params” :<Imprime forma de onda seleccionada, frecuencia y duty>
- Subrutina “print_offset” :<Imprime el signo y la tensión de offset>
- Subrutina “print_amplitude” :<Imprime la tensión de la forma de onda>
- Rutina “waveforms_menu”: <Carga la pantalla donde se selecciona y genera la forma de onda>
- Subrutina “recover_view” :<Imprime un menú circular de formas de onda según la selección previa>
- Subrutina “waveforms_circularmenu” :<Desplaza circularmente el menú con una flecha que indica la onda seleccionada>
- Subrutina “timer2_init” :<Reinicia el timer 2 (ante problemas por el cambio del valor de un registro asociado al PWM en tiempo de ejecución) >
- Subrutina “SampleRate_Algorithm” :<Determina la cantidad de muestras y el sample rate>
- Subrutina “Load_Square” :<Genera la forma de onda cuadrada>
- Subrutina “Load_Rectangular” :<Genera la forma de onda rectangular>
- Subrutina “Load_Sine”:<Genera la forma de onda senoidal>
- Subrutina “Load_Hav” :<Genera la forma de onda semiverseno>
- Subrutina “Load_Triangular” :<Genera la forma de onda triangular>
- Subrutina “Load_Sawtooth” :<Genera la forma de onda diente de sierra>
- Subrutina “Load_White” :<Genera la forma de onda de ruido blanco>
- Subrutina “HAL_DAC_Stop_DMA” :<Detiene el DAC>
- Subrutina “HAL_DAC_Start_DMA” :<Arranca el DAC>
- Rutina “frequency_menu” : <Carga la pantalla donde se determina la frecuencia>
- Subrutina “print_freqvalues”:<Imprime en pantalla las etiquetas y el valor de la frecuencia en Hz>
- Subrutina “print_arrowup”:<Imprime una flecha apuntando hacia arriba>
- Subrutina “waveforms_menu”:< Carga la pantalla donde se selecciona y genera la forma de onda >
- Subrutina “refresh”:<Recalcula la frecuencia a partir de la variación de los encoders >
- Rutina “dutycycle_menu” :<Carga la pantalla donde se determina el duty cycle>
- Subrutina “print_dutyvalues” :< Imprime en pantalla las etiquetas y el valor del duty cycle de manera porcentual >
- Subrutina “print_freqvalue” :< Imprime en pantalla las etiquetas y el valor de la frecuencia >
- Subrutina “print_arrowup” :< Imprime una flecha apuntando hacia arriba >
- Subrutina “refresh” :< Recalcula el duty cycle a partir de la variación de los encoders >
- Subrutina “print_hltimes” :<Imprime el duty cycle expresado en tiempos de actividad e inactividad>
- Subrutina “Load_Rectangular” :<Genera la fonda de onda rectangular>
- Rutina “arbwave_menu”: <Recibe y parsea los datos de la onda arbitraria>
- Subrutina “print_shifted” : <Imprime un string en una línea y posición particular en el display>
- Subrutina ” HAL_I2C_Slave_Receive_IT” :<Recibe bytes por I2C de manera no bloqueante y los guarda en un buffer>

- Subrutina ”params_parser” :<Obtiene la cantidad de muestras y sample rate del stream de información recibida por I2C>
- Subrutina ”flush_buffer” :< limpia el buffer>
- Subrutina “load_percentage” :<imprime el porcentaje de carga de la onda arbitraria>
- Subrutina “HAL_DAC_Stop_DMA” :<Detiene el DAC>
- Subrutina “HAL_DAC_Start_DMA” :<Arranca el DAC>

## 3.2.2 Descripción del funcionamiento de cada rutina

3.2.2.1 Función: main

Figura 19 - <Diagrama de flujo de la función main>

La función menú devuelve un puntero a uint16_t que es implementado como un vector dinamico donde se almacenan las muestras del DAC.

3.2.2.2 Función: menu

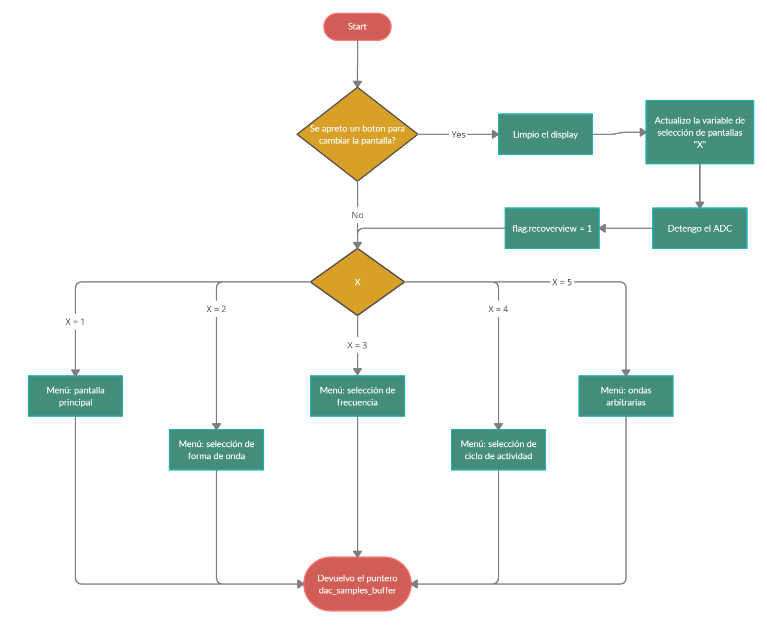
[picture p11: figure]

Figura 20 - <Diagrama de flujo de la función menú>

En la función “menu”, se procede a cambiar la pantalla de menú en el caso de presionar uno de los dos pulsadores. En base al pulsador presionado se determina la siguiente pantalla a mostrar, siguiendo un orden “circular”.

3.2.2.3 Función: main_screen

Figura 21 - <Diagrama de flujo de la funcion main_screen>

El flag de recoverview se setea en 1 cuando se requiere actualizar la información en pantalla y por lo tanto es necesario volver a “recuperar la vista” o actualizar los valores o la forma de onda a generar.

3.2.2.4 Función: waveforms_menu

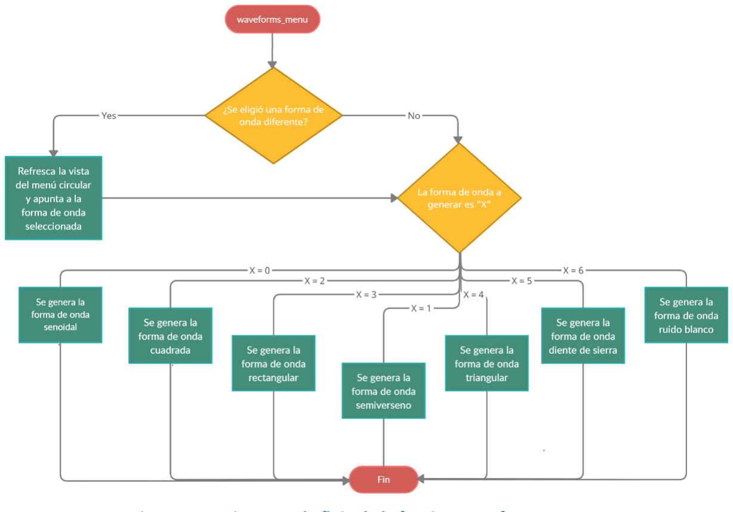
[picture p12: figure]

Figura 22 - <Diagrama de flujo de la funcion waveforms_menu>

Un flag denominado “reloadwave” se setea en 1 cuando ocurren cambios en el valor de la frecuencia o el duty cycle.
La función SampleRate_Algorithm se encarga de determinar la cantidad de muestras y el sample rate, para la gran mayoría de las formas de onda y se calcula como:

Variables
- frequency: valor de frecuencia deseado.
- samples: cantidad de muestras.
- f_calc: valor de frecuencia calculado.
- sp_calc: valor del sample rate calculado.
- arr_calc: valor del registro de autoreload del timer calculado.
- offset_calc: valor del offset, se obtiene del módulo de la diferencia entre frequency y f_calc

Consideraciones
- arr max: 65535 cuentas
- samples_max = 4000 muentras
- samples_min = 100 muestras
- samplerate_max = 10500000 Hz
- timer_fclock: 84000000 Hz
- offset = 5 Hz

Pasos

1. Se parte de suponer que se usará la mayor cantidad de muestras para representar la forma de onda
2. Se calcula el tentativo valor del registro de autoreload del timer como:

arr_calc = (timer_fclock / frequency) ∗ (1 / samples) – 1

3. Se calcula la frecuencia y el sample rate con el valor de arr calculado:

f_calc = ((timer_fclock) / (samples ∗ (arr + 1)))

sp_calc = ((timer_fclock) / ((arr + 1)))

4. Condiciones que se deben cumplir
a. El sp_calc debe ser menor o igual al 80% del samplerate_max.
b. El arr_calc debe ser menor o igual al arr_max .
c. La f_calc debe estar dentro de un rango de frequency +/- offset.
5. Luego se obtiene el valor de offset_calc

Se repiten los pasos del 2 al 5, decrementando la variable samples hasta encontrar el valor de offset_calc más pequeño que cumpla con las condiciones a,b y c del punto 4. Cuando samples sea menor a samples_min, en esa instancia, ya habremos obtenido el juego de valores óptimo de arr y sample_rate.

3.2.2.5 | Función: frequency_menu

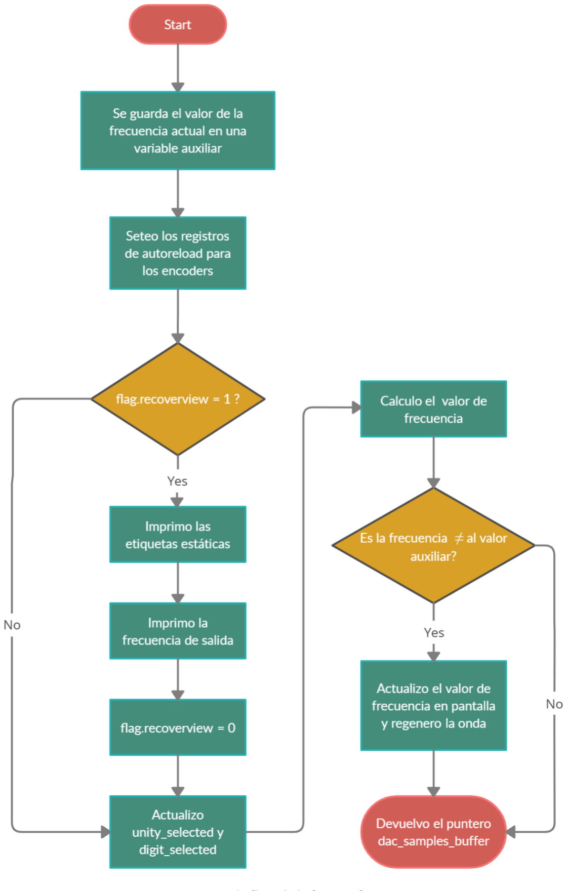
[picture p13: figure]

Figura 23 - <Diagrama de flujo de la funcion frequency_menu>

3.2.2.6 Función: dutycycle_menu

Figura 24 - <Diagrama de flujo de la funcion dutycycle_menu>

3.2.2.7 Función: arbwave_menu

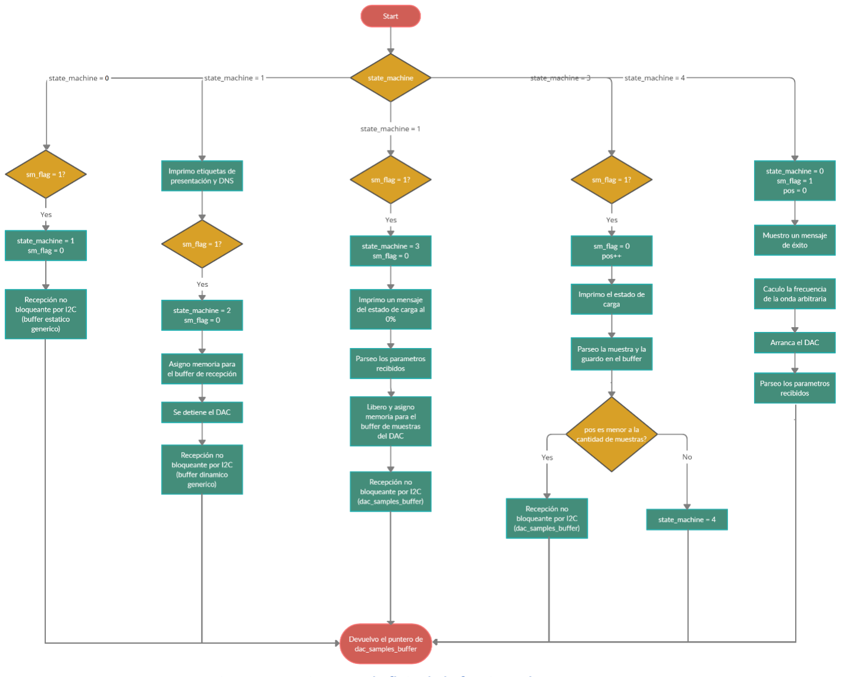
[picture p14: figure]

Figura 25 - <Diagrama de flujo de la funcion arbwave_menu>

Cada vez que se ejecuta la función de recepción no bloqueante por I2C y una recepción ocurre, la variable sm_flag se setea en 1 y se guarda en carácter en el buffer asignado en una función de callback. Si un error ocurre durante la recepción una función de callbacks de I2C notifica en el display el error.

## 3.3 Software propietario

Los archivos .csv que contienen los parámetros y muestras de ondas arbitrarias se crean utilizando un software de edición de formas de onda, el AFG Arbitrary Waveform Software de GwInstek.

## 3.3.1 AFG Arbitrary Waveform Software de GwInstek

Cuando se ejecuta el programa, un lienzo para dibujar formas de onda debajo aparecerá por detrás de un cuadro de diálogo de los parámetros iniciales, en donde se solicita la frecuencia de muestreo y el número de puntos de datos (longitud horizontal) se mostrará de la siguiente manera. Primero ingrese los parámetros para estar listo y editar la forma de onda.

Figura 26 - <Cuadro de parámetros del lienzo>

Después de la entrada de parámetros, el lienzo de forma de onda se muestra como la siguiente imagen. En la parte superior del lienzo, están disponibles todas las formas de ondas disponibles para dibujar.

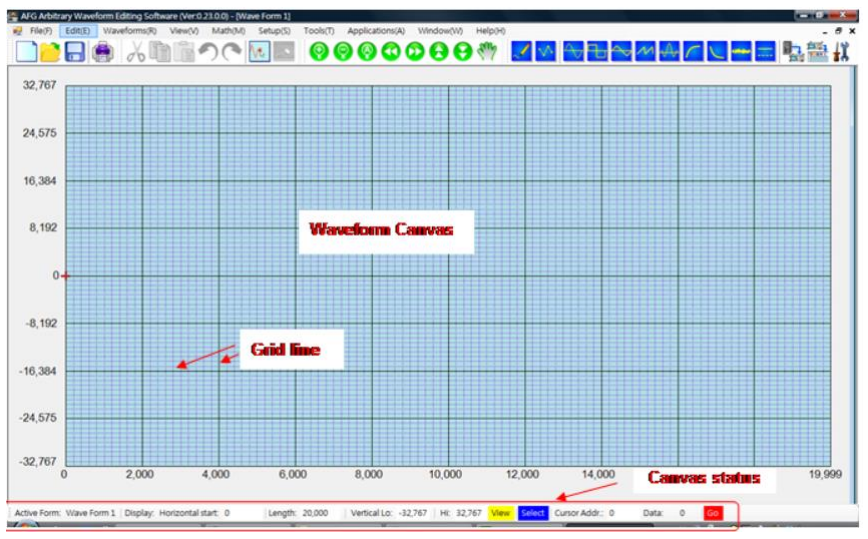
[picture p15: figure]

Figura 27 - <Vista del lienzo>

Al seleccionar una forma de onda predeterminada, aparecerá el siguiente cuadro de configuración:

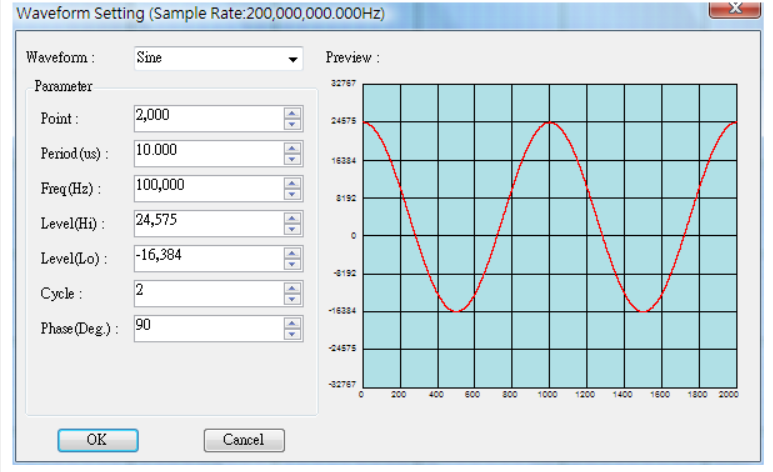
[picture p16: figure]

Figura 28 - <Cuadro de parámetros de la forma de onda>

- Punto: el número total de puntos de datos de la forma de onda. El rango es de 2 a la longitud máxima (decidido por la longitud máxima de edición del modelo).
- Periodo: el tiempo que tarda el total de puntos. Su fórmula es la siguiente:
Periodo = (el número total de puntos de datos / frecuencia de muestreo)
- Frecuencia: la inversa del periodo
- Nivel (Hi), Nivel (Lo): el valor pico positivo y negativo de la amplitud de la forma de onda. El rango corresponde a los bits del DAC (decididos por modelo).
- Ciclo: los tiempos de repetición de la forma de onda seleccionada se producen con los puntos de datos.
- Fase: retardo de fase de la forma de onda. El retraso de 90 grados se muestra en el ejemplo anterior.

Una vez terminad la edición, ir a File->Save as y guardar el archivo como .csv

El archivo de Excel tendrá el siguiente formato

Figura 29 - <Output del archivo .csv>

Para un uso compatible con el dispositivo el nivel (LO) debe ser como mínimo 0 y el nivel (HI), como máximo 4000. La cantidad de muestras menor a 4000 y el sample rate menor a 2MS/s.

# 4 Modo de operación

## 4.1 Menú

Como se mencionó en ítems anteriores, el equipo posee cinco pantallas con las cuales el usuario puede interactuar.
Al encender el equipo verá un mensaje de bienvenida, seguidamente se cargará la pantalla principal como se ilustra en la siguiente imagen. Aquí los encoders no tienen función alguna y solo es posible pulsar los botones de arriba o abajo para desplazarse a una pantalla diferente. Si gira cualquiera de los dos potenciómetros podrá ver cambios de tensión en amplitud y offset.

Figura 30 - <Pantalla principal>

Si usted se encontraba en la pantalla principal y pulsa el botón “ABAJO”, se cargará la pantalla de selección de formas de onda. Donde uno de los encoders permanecerá inhabilitado y el otro le permitirá desplazarse “en un loop circular” por todas las formas de onda disponibles y se generaran automáticamente ni bien sea indicada por una flecha.

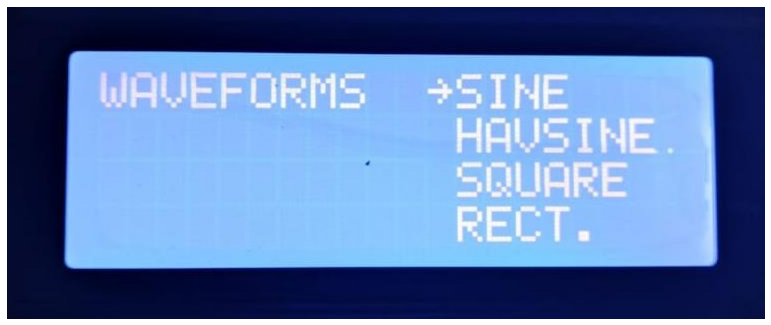
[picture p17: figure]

Figura 31 - <Pantalla de formas de onda>

Si usted se encontraba en la pantalla de selección de formas de onda y pulsa el botón “ABAJO”, se cargará la pantalla de selección de frecuencia. Aquí ambos encoders están habilitados para el uso del usuario. Uno de ellos permitirá desplazarse unidad por unidad y el otro, elegir un dígito de 0 a 9 mientras no se superen los límites de 1Hz mínimo y 20kHz máximo.

Figura 32 - <Pantalla de selección de frecuencia>

Si usted se encontraba en la pantalla de selección frecuencia, pulsa el botón “ABAJO” y la onda seleccionada es la forma de onda rectangular, se cargará la pantalla de duty cycle. Aquí ambos encoders están habilitados para el uso del usuario. Uno de ellos permitirá desplazarse unidad por unidad y el otro, elegir un dígito de 0 a 9 mientras no se superen los límites de 1% mínimo y 99% máximo.

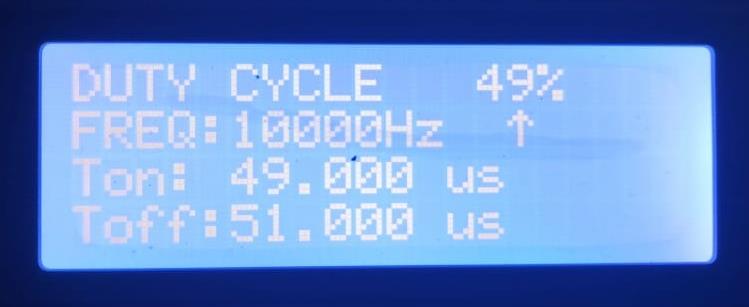
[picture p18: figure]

Figura 33 - <Pantalla de selección de duty cycle>

Si usted se encontraba en la pantalla de selección frecuencia, pulsa el botón “ABAJO” y la onda seleccionada es la forma de onda arbitraria, se cargará la pantalla de obtención de datos de ondas arbitrarias.
En la parte de inferior de la pantalla verá la reseña “Getting parameters”. Una vez que usted “seleccione” un archivo en el sitio web, podrá ver que la obtención de muestras está en curso ya que la reseña ahora será “Getting data values”. Cuando la operación termine volverá a observar el primer mensaje.

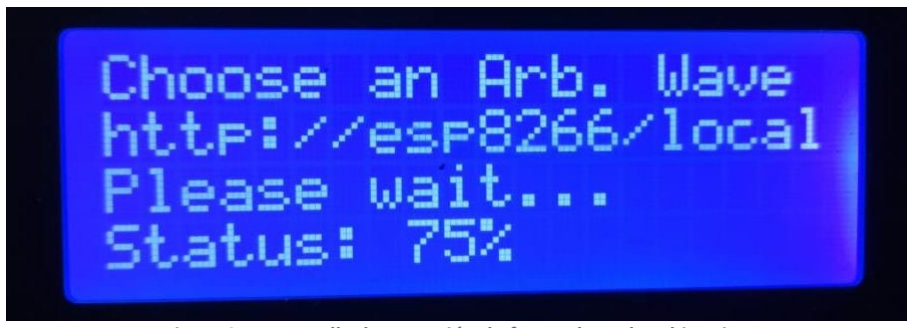
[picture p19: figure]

Figura 34 - <Pantalla de recepción de forma de onda arbitraria>

## 4.2 Sitio Web

Se montó un servidor web que se inicia al energizar la placa de desarrollo ESP8266 NodeMCU 1.0.
Debe accederse al sitio web desde http://esp8266.local/. No se necesitan credenciales.

Debajo de Permitted Files List se generarán los nombres de todos los archivos .csv que se encuentran alojados en la memoria flash del ESP8266 y que están disponibles para ser transmitidos por I2C al microcontrolador principal. Para ello, debe copiar y pegar el nombre del archivo incluyendo el carácter “/” y la extensión “.csv” en el edit o cuadro de texto.

Luego el usuario puede elegir entre enviar el archivo o eliminarlo de la memoria del módulo. Para ello tiene presentes dos botones auto-explicativos.

Si desea enviar una forma de onda que no está listada debe hacer click en “Seleccionar archivo” y elegir el archivo .csv, posteriormente hacer click en Upload. Si la carga ha sido efectiva será redirigido a una página de éxito y luego redirigido a la página principal nuevamente.

La operación de carga puede demorar hasta 40 segundos. Según la cantidad de muestras que contenga el archivo.

Para generar formas de ondas arbitrarias consulte el apartado “3.3 Software propietario”.

Figura 35 - <Sitio web de gestión de formas de onda arbitrarias>

# 5 Ensayos

## 5.1 Ensayo de frecuencias

## 5.1.1 Ensayo de frecuencia a 1Hz y 20kHz

En los siguientes ensayos se generó funciones a 1Hz y 20kHz a la amplitud máxima de 20Vpp.

| Valores medidos de frecuencia [Hz]*
| 1 | 50 | 150 | 550 | 1050 | 5050 | 10050 | 15050 | 20000
Funciones generadas a partir del DAC | 1 | 49,9021 | 149,706 | 549,902 | 1049,99 | 5050,88 | 10050,8 | 15045,7 | 20000,9
Funciones generadas a partir del PWM | 1 | 49.9021 | 150,684 | 549,902 | 1049,88 | 5049,99 | 10051,8 | 15052,8 | 20001,9

*La frecuencia fue medida con un osciloscopio Siglent SDS 1072CNL+

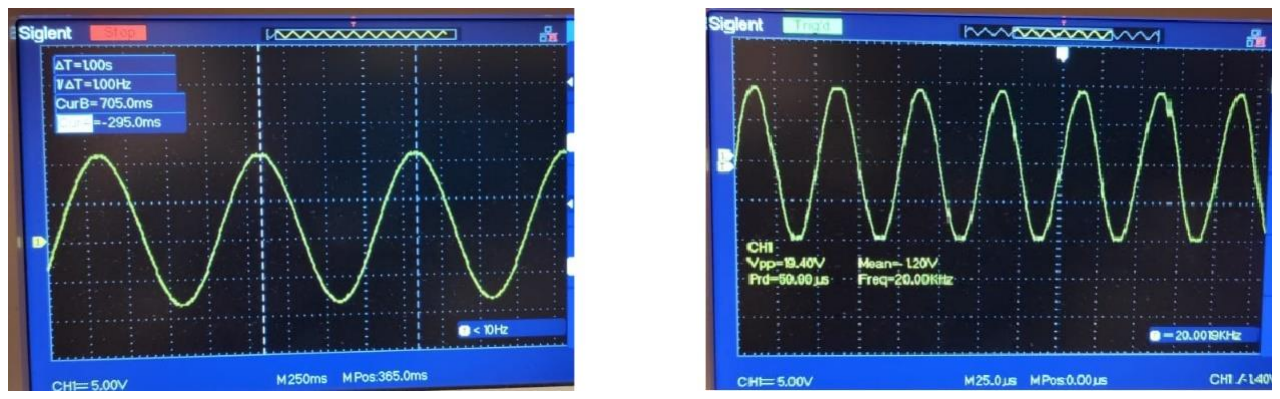
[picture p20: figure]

Figura 36 - <Forma de onda: seno, 1 Hz (izquierda) y 20 kHz(dererecha)>

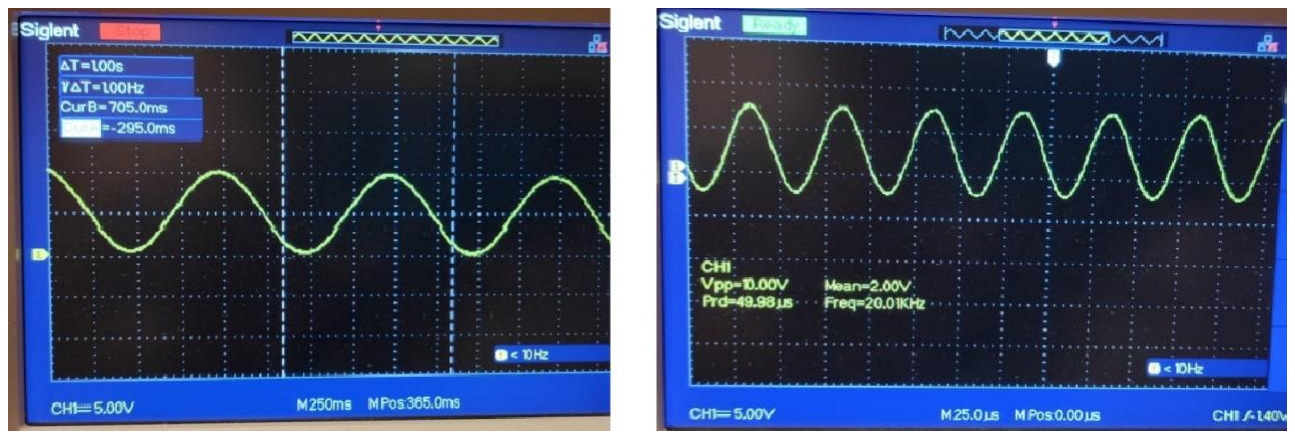
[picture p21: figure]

Figura 37 - < Forma de onda: semiverseno, 1 Hz (izquierda) y 20 kHz (dererecha)>

Figura 38 - < Forma de onda: cuadrada, 1 Hz (izquierda) y 20 kHz (dererecha)>

Figura 39 - < Forma de onda: rectangular, 1 Hz;DUT:20% (izquierda) y 20 kHz;DUT:50% (dererecha)>

Figura 40 - < Forma de onda: triangular, 1 Hz (izquierda) y 20 kHz (dererecha)>

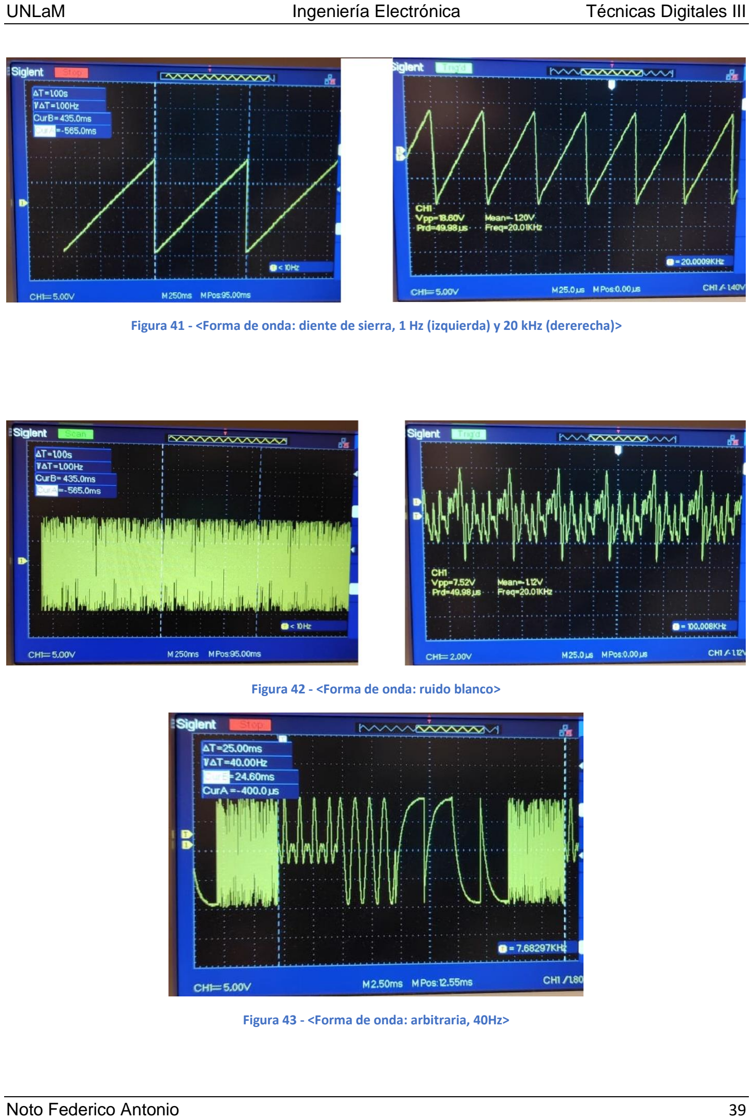
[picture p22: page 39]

Figura 41 - <Forma de onda: diente de sierra, 1 Hz (izquierda) y 20 kHz (dererecha)>

Figura 42 - <Forma de onda: ruido blanco>

Figura 43 - <Forma de onda: arbitraria, 40Hz>

## 5.2 Ensayo de amplitudes

La señal del pin PA4 [DAC] tiene una amplitud de 2.92V

La señal del pin PA5 [PWM] tiene una amplitud de 3.14V

| Amplitud de señal | Amplitud de offset | AmpDac | OffsetDac | PolarityDac
Teórica mínima | 0.19mVpp | -5V | 0V | 0V | 0V
Teórica máxima | 19.85Vpp | +5V | 3V | 3V | 3V
Medida mínima | 50mV | -5.2V | 0.8mV | 0V/1.58V | -40mV
Medida máxima | 19.8Vpp | 5.26V | 3.04V | 3.2V | 3.2V

# 6 Conclusiones

Se ha desarrollado un equipo generador de funciones y ondas arbitrarias WiFi que obedece en gran mayoría con las especificaciones entregadas en el preinforme, incluso se han agregado más formas de onda de las acordadas en un primer momento. En contraste, a lo largo del proyecto, nos hemos encontrado con ciertas cuestiones que evitan que el proyecto cumpla con todos los requerimientos.

Ha sido un gran desafío en cuanto a software desde varios puntos de vista. El desarrollo del menú llevó mucho tiempo e incluso sufrió grandes modificaciones en cuanto a la estructura del código, con el pasar de los meses, se buscó realizar un código limpio, corto y eficiente.

El algoritmo para determinar la cantidad de muestras y el sample rate necesario según la frecuencia deseada es otro de los puntos en los que se incurrió en demoras.

Además del cambio de IDE, de KEIL a STM32CubeIDE, como así también la incorporación de porciones de código en C++ implementando clases y la optimización del envío de un gran volumen de cadenas de caracteres por I2C, dado que al querer asignar/liberar memoria para almacenar todos los caracteres que pueden encontrarse en un archivo de muestras, de alrededor de 30k caracteres, ocurrían hardfaults. La solución fue enviar un carácter por vez hasta completar la muestra y parsearla y repetir este proceso hasta el fin del archivo.

También ha sido un desafío el diseño de la electrónica analógica, donde el problema principal es el desacople de la señal. El desacople no es perfecto, es decir, la señal no se centra en 0V como lo esperado, la variación puede ser entre 200 mV y 1V. Para la señal de onda rectangular el desacople es también es deficiente al modificar el ciclo de actividad. Además, creemos que la amplificación y la medición son puntos mejorables en cuanto al ruido, precisión de las ganancias, la tecnología del potenciómetro, el diseño de los PCB, entre otros.

# 7 Referencias

1. Link: Signal Generator Fundamentals-https://engineering.case.edu/lab/circuitslab/sites/engineering.case.edu.lab.circuitslab/files/dos/Signal_Generator_Fundamentals-_Tektronix.pdf (https://engineering.case.edu/lab/circuitslab/sites/engineering.case.edu.lab.circuitslab/files/do%20s/Signal_Generator_Fundamentals-_Tektronix.pdf)
2. Link: High Speed, Digital to Analog Converters Basics -https://www.ti.com/lit/an/slaa523a/slaa523a.pdf
3. Link: A Technical Tutorial on Digital Signal Synthesis - https://www.ieee.li/pdf/essay/dds.pdf
4. Link: Fundamentals of Direct Digital Synthesis (DDS) -https://www.analog.com/media/en/training-seminars/tutorials/MT-085.pdf

# 8 ANEXO

## 8.1.1 Esquemáticos

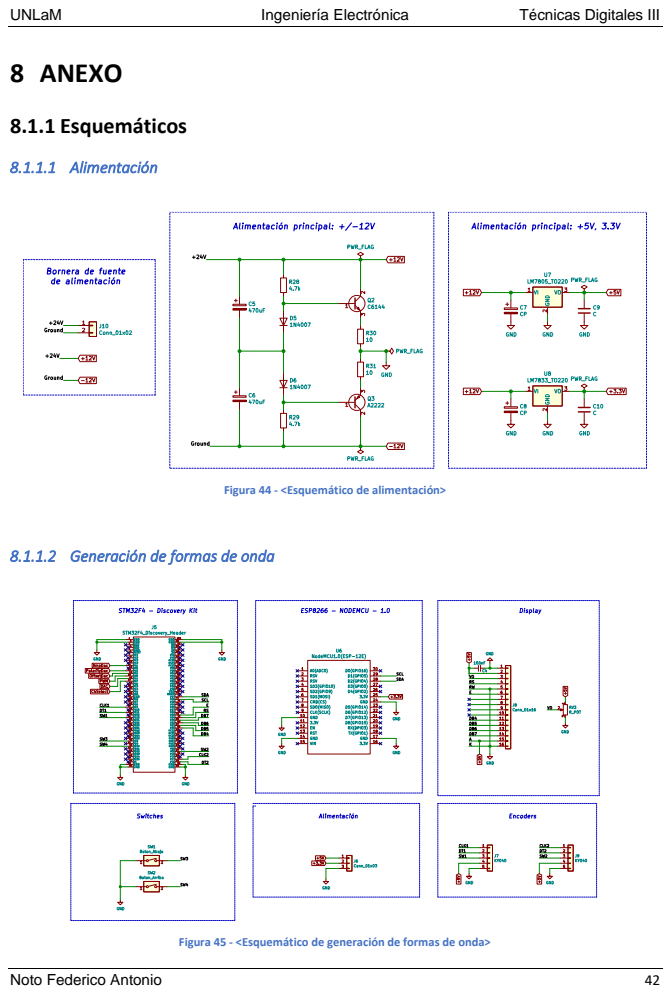
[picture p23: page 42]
8.1.1.1 Alimentación

Figura 44 - <Esquemático de alimentación>

8.1.1.2 Generación de formas de onda

Figura 45 - <Esquemático de generación de formas de onda>

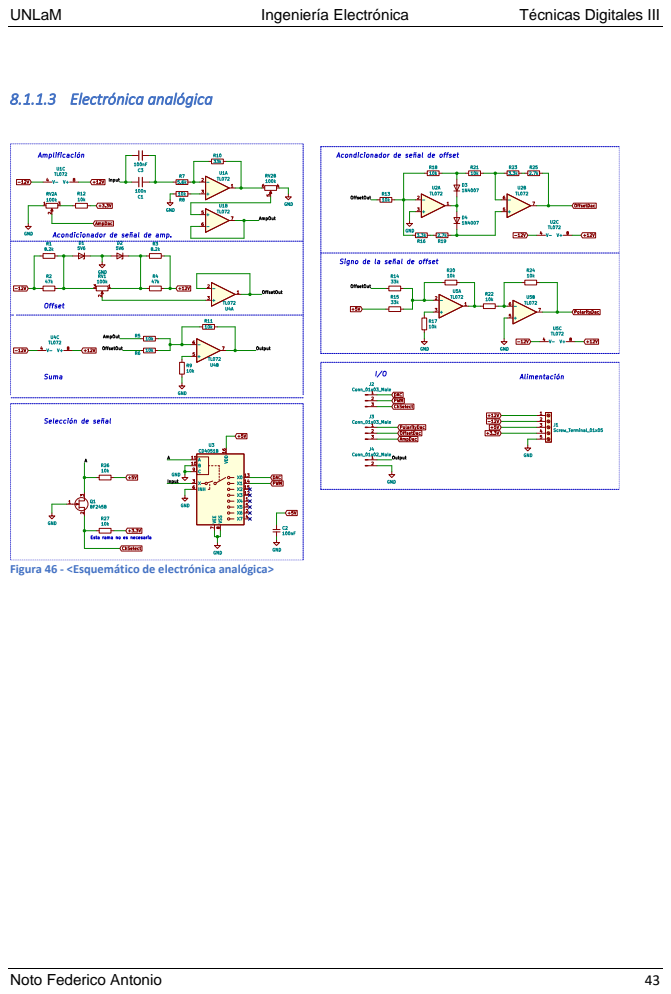
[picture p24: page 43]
8.1.1.3 Electrónica analógica

Figura 46 - <Esquemático de electrónica analógica>

## 8.1.2 Circuitos impresos

8.1.2.1 Generación de formas de onda

Figura 47 - <PCB de placa generadora de formas de onda>

8.1.2.2 Electrónica analógica

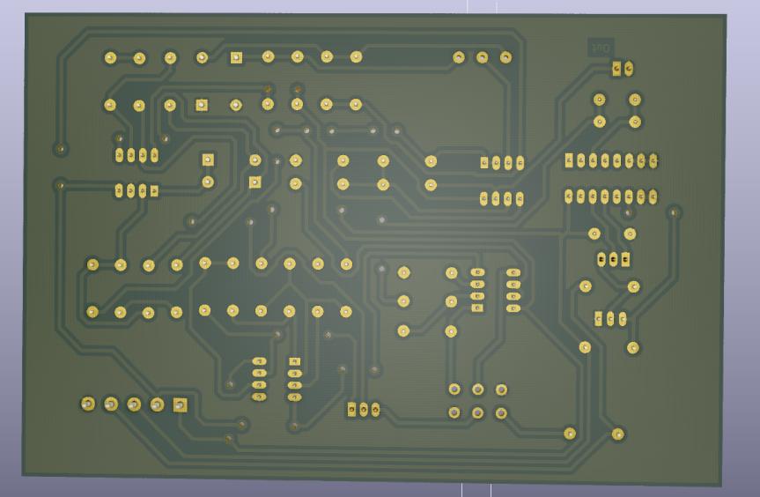
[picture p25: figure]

Figura 48 - <PCB de placa de electrónica analógica>

Universidad Nacional de La Matanza Técnicas Digitales III

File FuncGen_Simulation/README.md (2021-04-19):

# Simulación del modulo amplificador del proyecto de generación de funciones y ondas arbitrarias WiFi

Sistema operativo: Windows 10 / Software: LTSpice

La simulacion consta de varios bloques:

1. Selección de la señal con un multiplexor
2. Amplificación de la señal elegida
3. Generación de una señal de offset
4. Suma de 2 y 3 resultando en la salida 
5. Medición de la tensión de amplificación
6. Medición de la tensión de offset
7. Obtención del signo de la tensión de offset

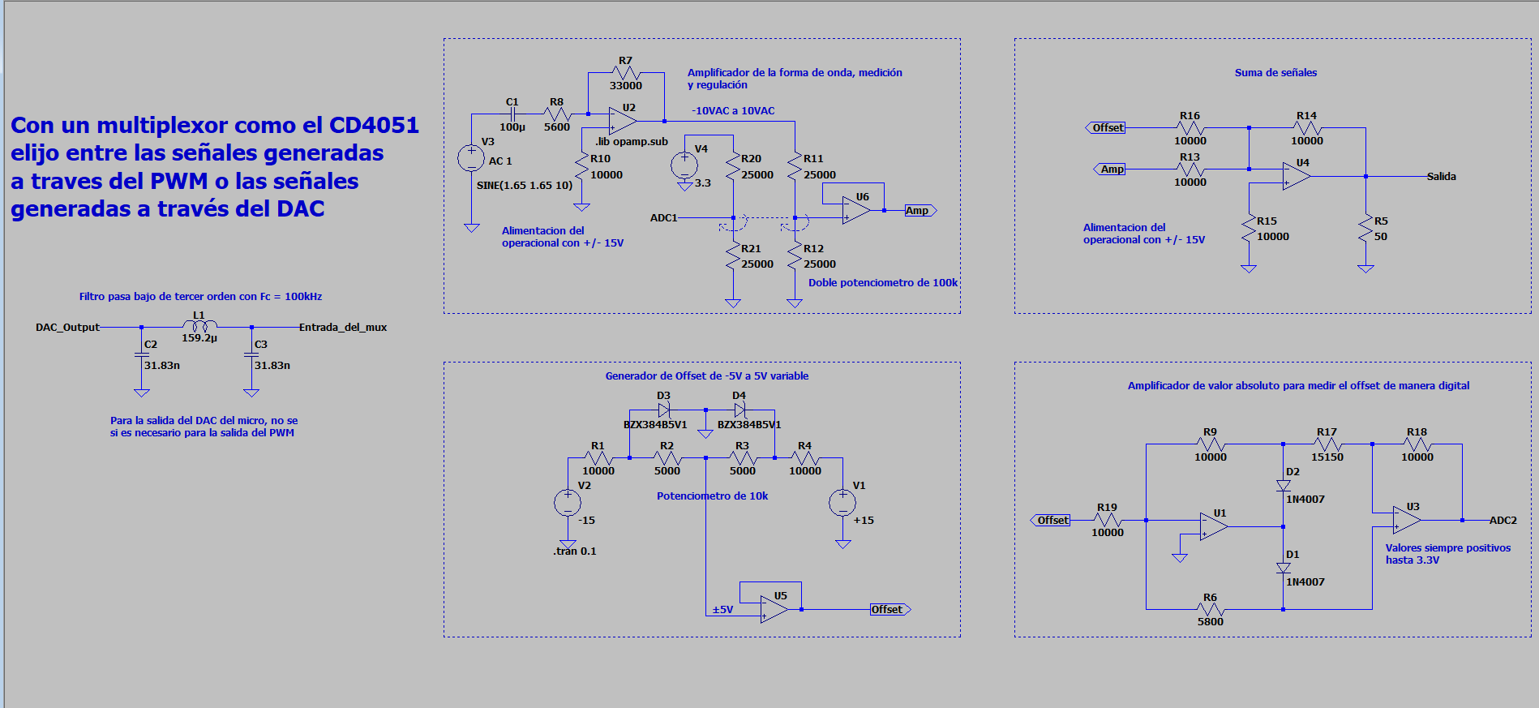
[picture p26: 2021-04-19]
FuncGen_Simulation/image.png

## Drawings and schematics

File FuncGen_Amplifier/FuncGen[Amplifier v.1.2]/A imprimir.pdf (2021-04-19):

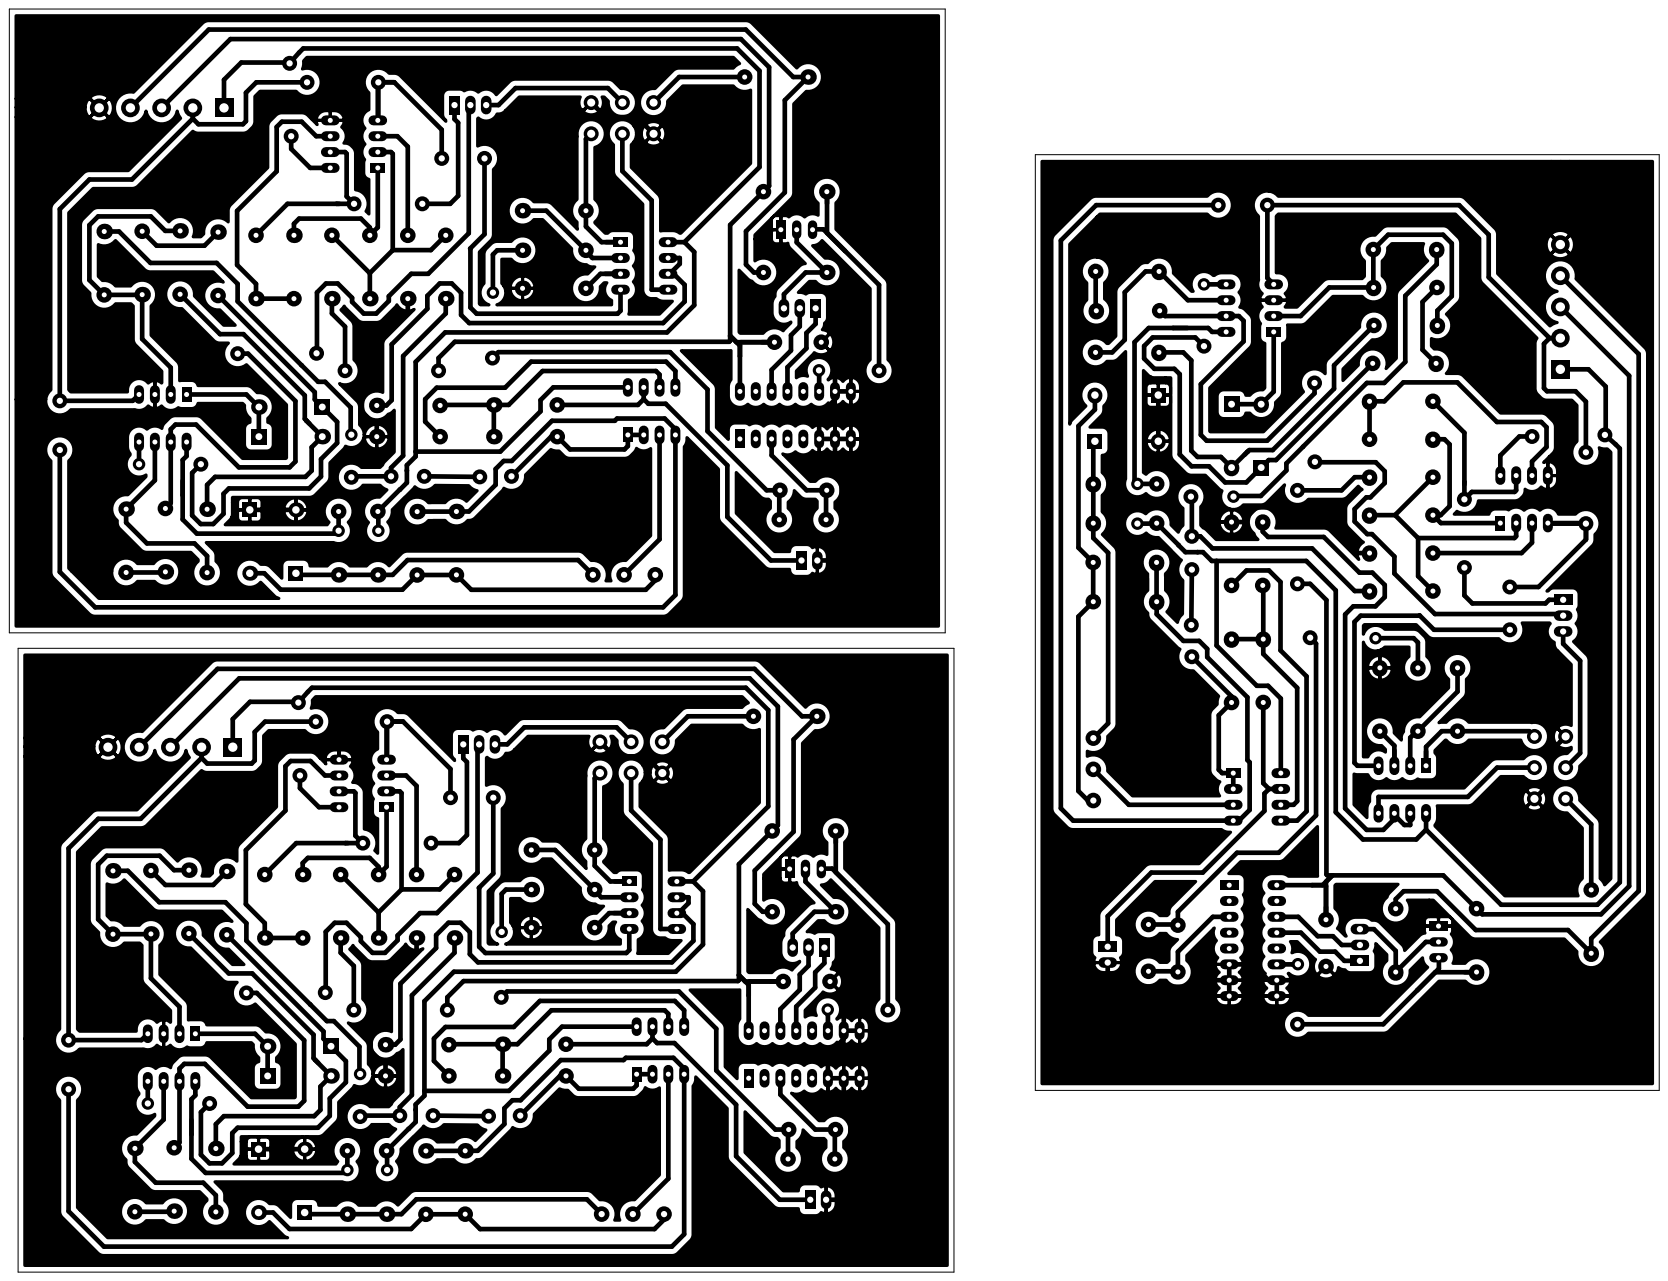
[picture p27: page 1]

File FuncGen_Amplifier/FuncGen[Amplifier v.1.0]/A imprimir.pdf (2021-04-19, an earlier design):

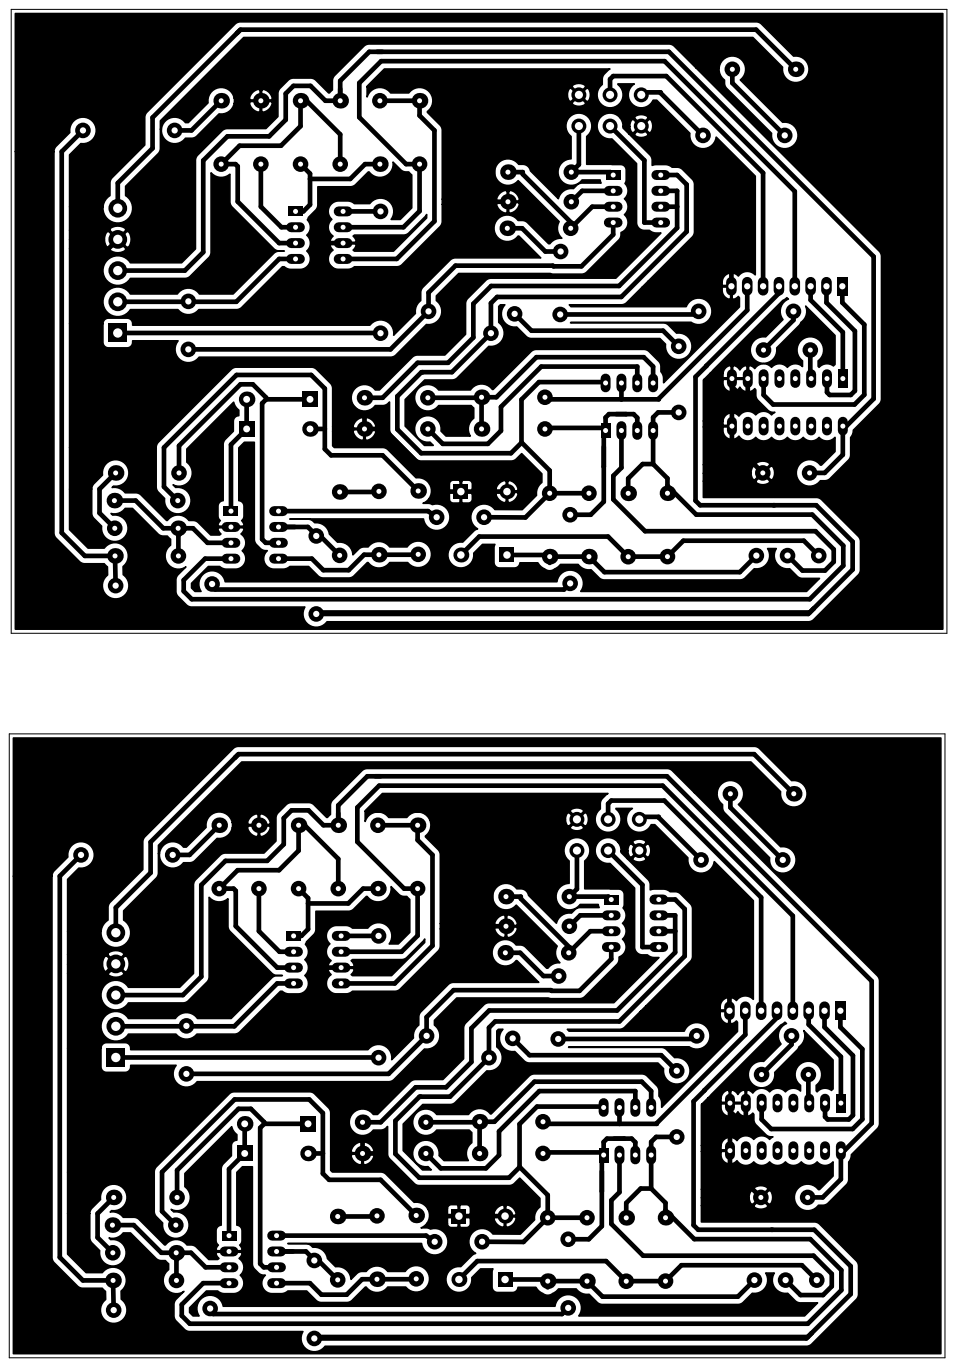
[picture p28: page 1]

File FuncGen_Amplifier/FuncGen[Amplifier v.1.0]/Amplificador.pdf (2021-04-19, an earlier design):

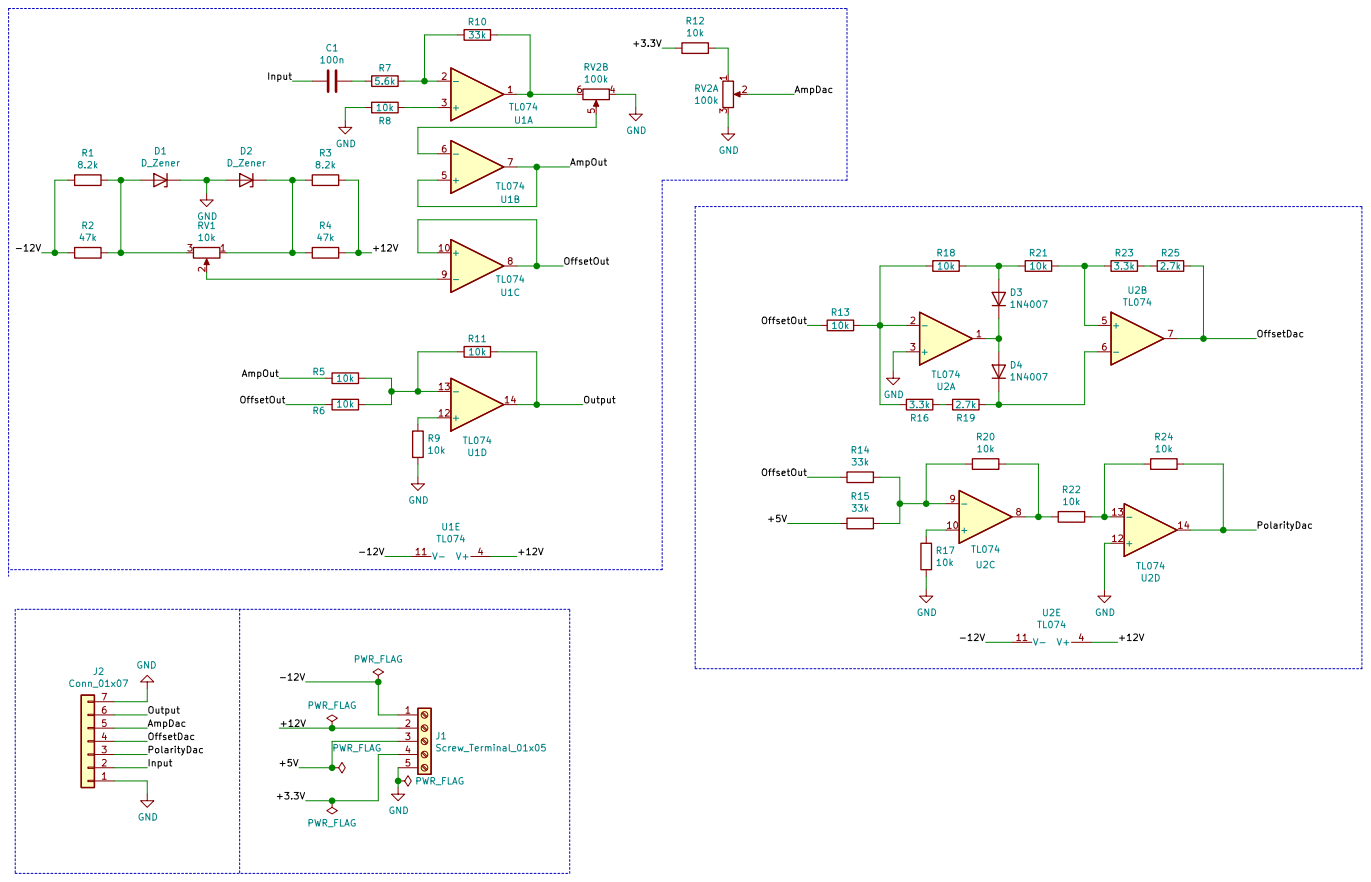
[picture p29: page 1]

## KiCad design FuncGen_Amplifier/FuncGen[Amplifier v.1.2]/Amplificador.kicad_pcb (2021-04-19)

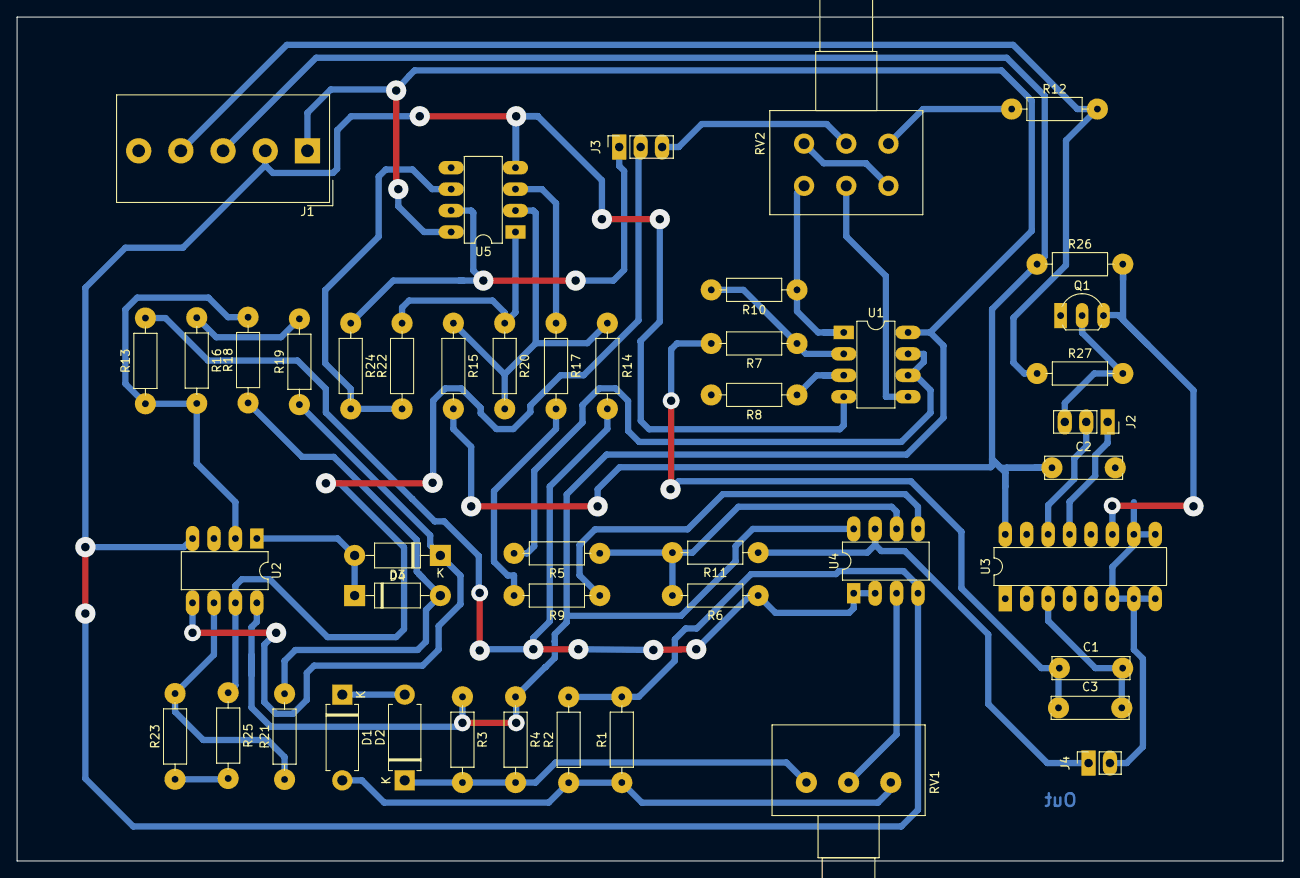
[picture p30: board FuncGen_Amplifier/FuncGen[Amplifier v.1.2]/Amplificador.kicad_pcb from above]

Board: 2 copper layers, 150.0 x 100.0 mm, 46 parts (0 on the bottom side), 38 nets.

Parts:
C1: 100n; C_Rect_L9.0mm_W2.5mm_P7.50mm_MKT
C2, C3: 100nF; C_Rect_L9.0mm_W2.5mm_P7.50mm_MKT
D1, D2: D_Zener; D_DO-15_P10.16mm_Horizontal
D3, D4: 1N4007; D_DO-41_SOD81_P10.16mm_Horizontal
J1: Screw_Terminal_01x05; Altech_AK300_1x05_P5.00mm_45-Degree
J2, J3: Conn_01x03_Male; PinSocket_1x03_P2.54mm_Vertical
J4: Conn_01x02_Male; PinSocket_1x02_P2.54mm_Vertical
Q1: BF245B; TO-92L_Inline_Wide
R1, R3: 8.2k; R_Axial_DIN0207_L6.3mm_D2.5mm_P10.16mm_Horizontal
R2, R4: 47k; R_Axial_DIN0207_L6.3mm_D2.5mm_P10.16mm_Horizontal
R5, R6, R8, R9, R11, R12, R13, R17, R18, R20, R21, R22, R24, R26, R27: 10k; R_Axial_DIN0207_L6.3mm_D2.5mm_P10.16mm_Horizontal
R7: 5.6k; R_Axial_DIN0207_L6.3mm_D2.5mm_P10.16mm_Horizontal
R10, R14, R15: 33k; R_Axial_DIN0207_L6.3mm_D2.5mm_P10.16mm_Horizontal
R16, R23: 3.3k; R_Axial_DIN0207_L6.3mm_D2.5mm_P10.16mm_Horizontal
R19, R25: 2.7k; R_Axial_DIN0207_L6.3mm_D2.5mm_P10.16mm_Horizontal
RV1: 10k; Potentiometer_Alps_RK163_Single_Horizontal
RV2: 100k; Potentiometer_Alps_RK163_Dual_Horizontal
U1, U2, U4, U5: TL072; DIP-8_W7.62mm_LongPads
U3: CD4051B; DIP-16_W7.62mm_LongPads

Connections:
/+3.3V: J1.4, R12.2, R27.1
/+5V: C2.1, J1.3, R15.2, R26.1, U3.16
/+12V: J1.1, R3.1, R4.1, U1.8, U2.8, U4.8, U5.8
/-12V: J1.2, R1.2, R2.2, U1.4, U2.4, U4.4, U5.4
/A: Q1.3, R26.2, U3.11
/AmpDac: J3.3, RV2.2
/AmpOut: R5.2, U1.6, U1.7
/ChSelect: J2.3, Q1.2, R27.2
/DACInput: J2.1, U3.13
/Input: C1.2, C3.2, U3.3
/OffsetDac: J3.2, R25.1, U2.7
/OffsetOut: R6.1, R13.2, R14.2, U4.1, U4.2
/Output: J4.1, R11.1, U4.7
/PWMInput: J2.2, U3.14
/PolarityDac: J3.1, R24.1, U5.7
GND: C2.2, D1.1, D2.2, J1.5, J4.2, Q1.1, R8.2, R9.2, R17.2, RV2.3, RV2.4, U2.3, U3.6, U3.7, U3.8, U3.9, U3.10, U5.5
unnamed: C1.1, C3.1, R7.2
unnamed: D1.2, R1.1, R2.1, RV1.3
unnamed: D2.1, R3.2, R4.2, RV1.1
unnamed: D3.1, D4.2, U2.1
unnamed: D3.2, R18.1, R21.2
unnamed: D4.1, R19.1, U2.5
unnamed: R8.1, U1.3
unnamed: R9.1, U4.5
unnamed: R10.1, RV2.6, U1.1
unnamed: R7.1, R10.2, U1.2
unnamed: R5.1, R6.2, R11.2, U4.6
unnamed: R12.1, RV2.1
unnamed: R13.1, R16.2, R18.2, U2.2
unnamed: R14.1, R15.1, R20.2, U5.2
unnamed: R16.1, R19.2
unnamed: R17.1, U5.3
unnamed: R20.1, R22.2, U5.1
unnamed: R21.1, R23.2, U2.6
unnamed: R22.1, R24.2, U5.6
unnamed: R23.1, R25.2
unnamed: RV1.2, U4.3
unnamed: RV2.5, U1.5

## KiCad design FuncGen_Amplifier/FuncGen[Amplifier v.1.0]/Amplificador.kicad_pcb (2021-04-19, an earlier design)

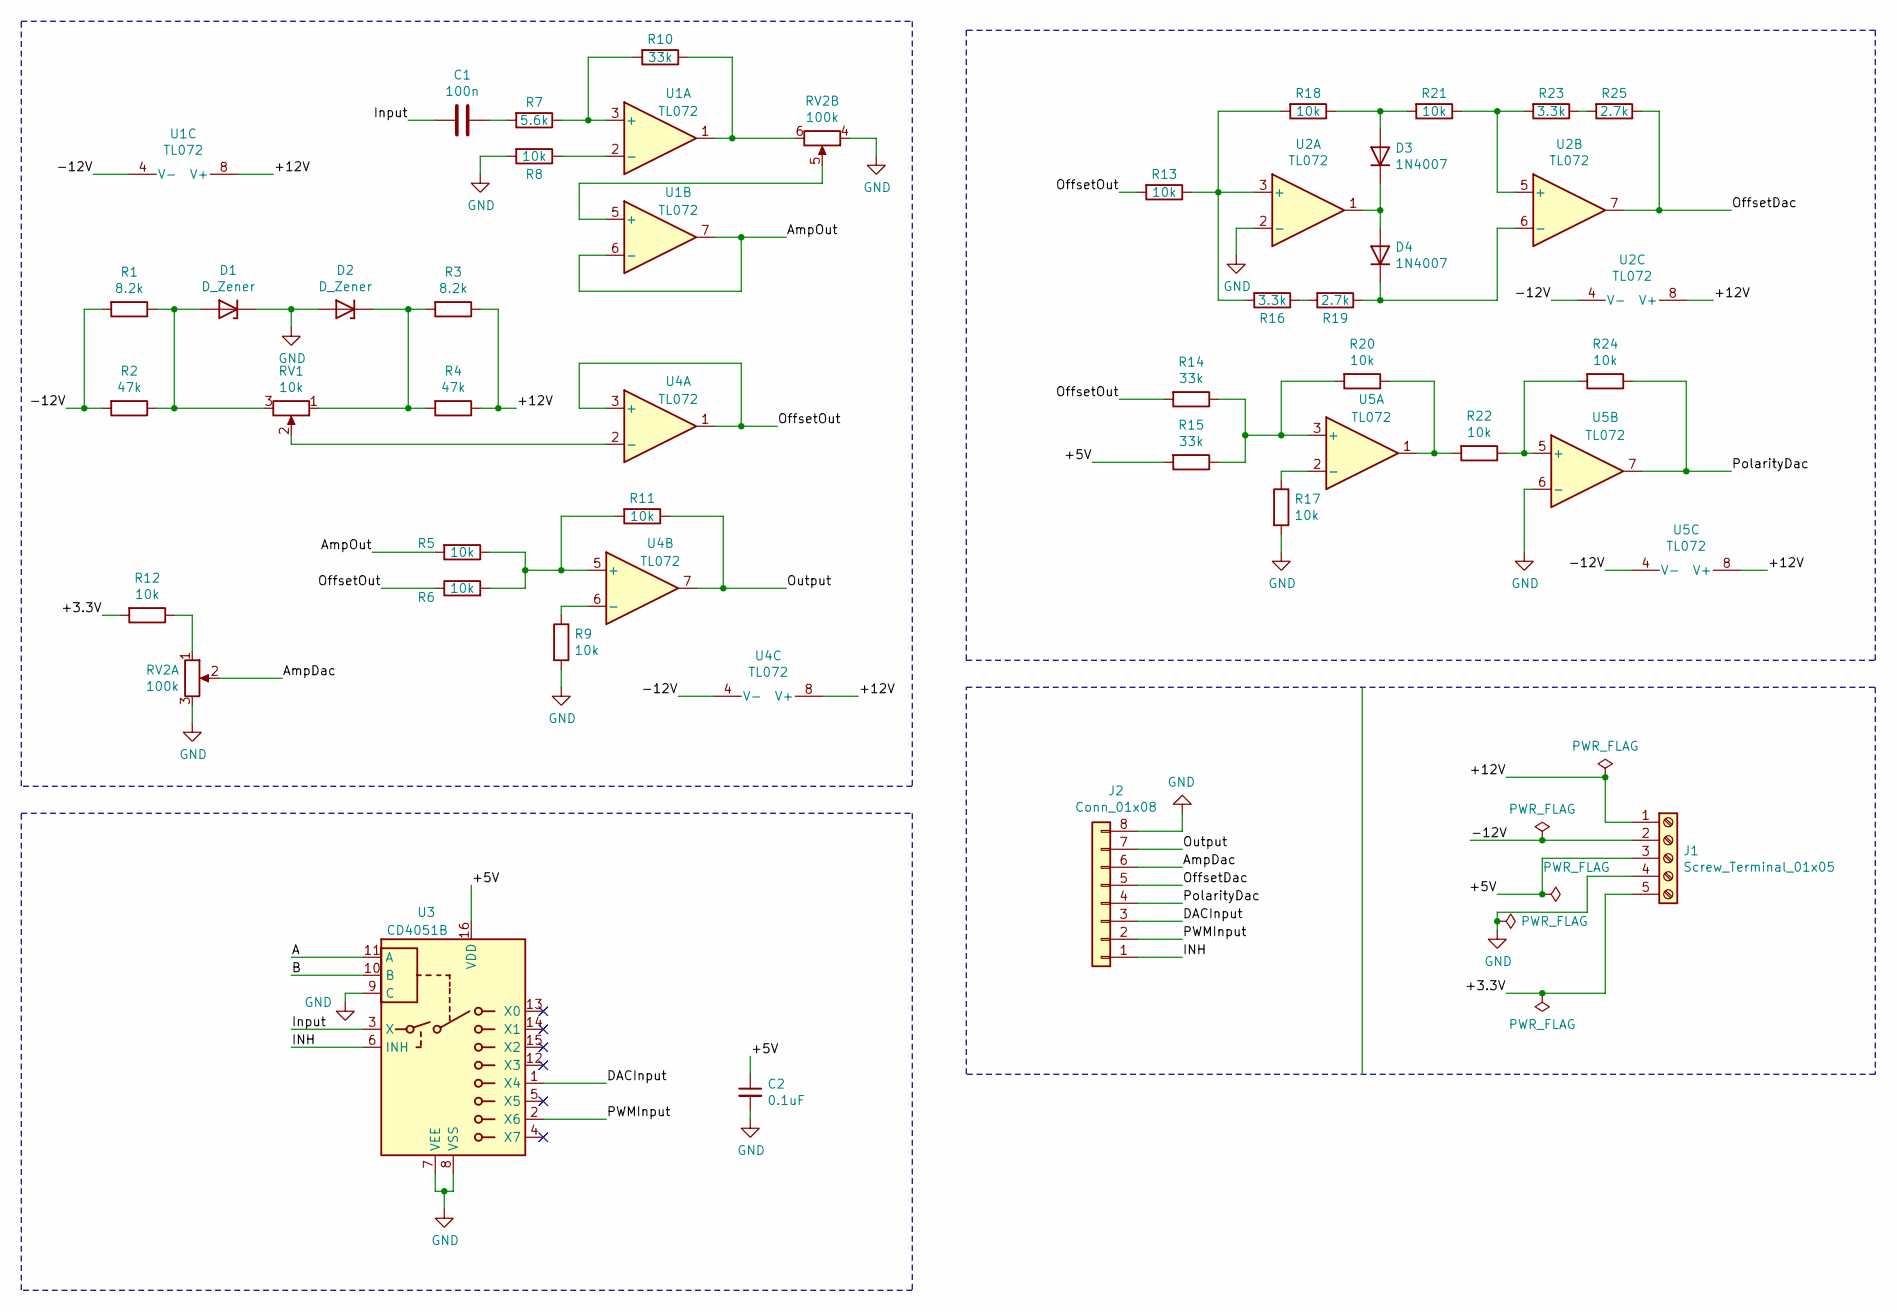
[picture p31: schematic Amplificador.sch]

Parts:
C1: 100n; C_Rect_L9.0mm_W2.5mm_P7.50mm_MKT
C2: 0.1uF; C_Rect_L9.0mm_W2.5mm_P7.50mm_MKT
D1, D2: D_Zener; D_DO-15_P10.16mm_Horizontal
D3, D4: 1N4007; D_DO-41_SOD81_P10.16mm_Horizontal
J1: Screw_Terminal_01x05; Altech_AK300_1x05_P5.00mm_45-Degree
J2: Conn_01x08; PinHeader_1x08_P2.54mm_Vertical
R1, R3: 8.2k; R_Axial_DIN0207_L6.3mm_D2.5mm_P10.16mm_Horizontal
R2, R4: 47k; R_Axial_DIN0207_L6.3mm_D2.5mm_P10.16mm_Horizontal
R5, R6, R8, R9, R11, R12, R13, R17, R18, R20, R21, R22, R24: 10k; R_Axial_DIN0207_L6.3mm_D2.5mm_P10.16mm_Horizontal
R7: 5.6k; R_Axial_DIN0207_L6.3mm_D2.5mm_P10.16mm_Horizontal
R10, R14, R15: 33k; R_Axial_DIN0207_L6.3mm_D2.5mm_P10.16mm_Horizontal
R16, R23: 3.3k; R_Axial_DIN0207_L6.3mm_D2.5mm_P10.16mm_Horizontal
R19, R25: 2.7k; R_Axial_DIN0207_L6.3mm_D2.5mm_P10.16mm_Horizontal
RV1: 10k; Potentiometer_Alps_RK163_Single_Horizontal
RV2: 100k; Potentiometer_Alps_RK163_Dual_Horizontal
U1, U2, U4, U5: TL072; DIP-8_W7.62mm_LongPads
U3: CD4051B; DIP-16_W7.62mm_LongPads

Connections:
/+3.3V: J1.5, R12.2
/+5V: C2.1, J1.3, R15.2, U3.16 (VDD)
/+12V: J1.1, R3.1, R4.1, U1.8 (V+), U2.8 (V+), U4.8 (V+), U5.8 (V+)
/-12V: J1.2, R1.2, R2.2, U1.4 (V-), U2.4 (V-), U4.4 (V-), U5.4 (V-)
/A: U3.11 (A)
/AmpDac: J2.6, RV2.2
/AmpOut: R5.2, U1.6 (-), U1.7
/B: U3.10 (B)
/DACInput: J2.3, U3.1 (X4)
/INH: J2.1, U3.6 (INH)
/Input: C1.2, U3.3 (X)
/OffsetDac: J2.5, R25.1, U2.7
/OffsetOut: R6.1, R13.2, R14.2, U4.1, U4.3 (+)
/Output: J2.7, R11.1, U4.7
/PWMInput: J2.2, U3.2 (X6)
/PolarityDac: J2.4, R24.1, U5.7
GND: C2.2, D1.1 (K), D2.2 (A), J1.4, J2.8, R8.2, R9.2, R17.2, RV2.3, RV2.4, U2.2 (-), U3.7 (VEE), U3.8 (VSS), U3.9 (C), U5.6 (-)
unnamed: C1.1, R7.2
unnamed: D1.2 (A), R1.1, R2.1, RV1.3
unnamed: D2.1 (K), R3.2, R4.2, RV1.1
unnamed: D3.1 (K), D4.2 (A), U2.1
unnamed: D3.2 (A), R18.1, R21.2
unnamed: D4.1 (K), R19.1, U2.6 (-)
unnamed: R8.1, U1.2 (-)
unnamed: R9.1, U4.6 (-)
unnamed: R10.1, RV2.6, U1.1
unnamed: R7.1, R10.2, U1.3 (+)
unnamed: R5.1, R6.2, R11.2, U4.5 (+)
unnamed: R12.1, RV2.1
unnamed: R13.1, R16.2, R18.2, U2.3 (+)
unnamed: R14.1, R15.1, R20.2, U5.3 (+)
unnamed: R16.1, R19.2
unnamed: R17.1, U5.2 (-)
unnamed: R20.1, R22.2, U5.1
unnamed: R21.1, R23.2, U2.5 (+)
unnamed: R22.1, R24.2, U5.5 (+)
unnamed: R23.1, R25.2
unnamed: RV1.2, U4.2 (-)
unnamed: RV2.5, U1.5 (+)

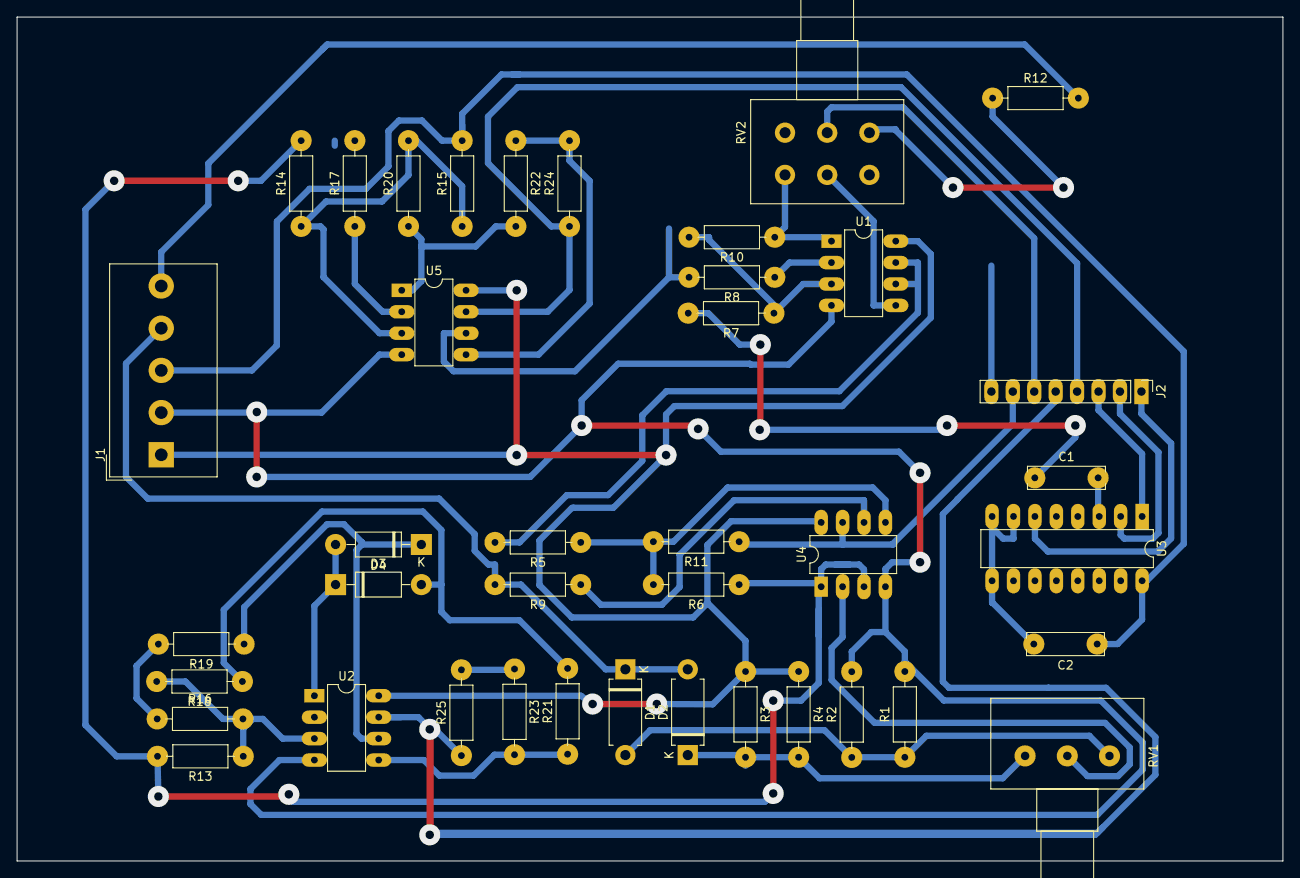
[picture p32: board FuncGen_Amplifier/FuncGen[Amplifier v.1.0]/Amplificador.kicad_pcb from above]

Board: 2 copper layers, 150.0 x 100.0 mm, 40 parts (0 on the bottom side), 37 nets.

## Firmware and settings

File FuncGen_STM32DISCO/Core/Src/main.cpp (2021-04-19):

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
/* Includes ------------------------------------------------------------------*/
#include "main.h"

/* USER CODE BEGIN Includes */
#include "lcd.h"
#include "menu.h"
#include "common_waves.h"
#include "push_buttons.h"
#include "arb.h"
/* USER CODE END Includes */

/* USER CODE BEGIN PTD */
#define INITIAL_FREQUENCY	10000
#define INITIAL_AMPLITUDE	3900
#define INITIAL_OFFSET		0
#define INITIAL_DUTY_CYCLE	50
#define WELCOMESCREEN_TIME	20
#define ON 					1
#define OFF					0
#define IDLE				0
#define CHECK				1
#define PUSH				2
#define NPUSH				3
#define DEBOUNCINGTIME		100

/* USER CODE END PTD */

ADC_HandleTypeDef hadc3;
DMA_HandleTypeDef hdma_adc3;

DAC_HandleTypeDef hdac;
DMA_HandleTypeDef hdma_dac1;

I2C_HandleTypeDef hi2c1;

TIM_HandleTypeDef htim1;
TIM_HandleTypeDef htim2;
TIM_HandleTypeDef htim3;
TIM_HandleTypeDef htim6;
TIM_HandleTypeDef htim8;

/* USER CODE BEGIN PV */
GPIO_PinState pin_state;

volatile uint16_t button_callback;
int8_t flag_callback_menu = 0;
int counter = 0, pressed_button = 0;

int *lcd_cnt = 0, *ldc_init_flag = 0, *lcd_wr_flag = 0, *lcd_wr_instr4bits_flag = 0, *lcd_posic_flag = 0;
char *aux_aux = 0, *aux_address = 0;
unsigned char *aux_dato = 0;

struct wave_param param = { INITIAL_FREQUENCY, INITIAL_AMPLITUDE, INITIAL_OFFSET, INITIAL_DUTY_CYCLE };

/* USER CODE END PV */

void SystemClock_Config(void);
static void MX_GPIO_Init(void);
static void MX_DMA_Init(void);
static void MX_I2C1_Init(void);
static void MX_DAC_Init(void);
static void MX_TIM1_Init(void);
static void MX_TIM2_Init(void);
static void MX_TIM3_Init(void);
static void MX_TIM6_Init(void);
static void MX_TIM8_Init(void);
static void MX_ADC3_Init(void);
/* USER CODE BEGIN PFP */
void welcome(void);
void button_check(void);
/* USER CODE END PFP */

/**
  * @brief  The application entry point.
  * @retval int
  */
int main(void)
{
  /* MCU Configuration--------------------------------------------------------*/

  /* Reset of all peripherals, Initializes the Flash interface and the Systick. */
  HAL_Init();

  /* Configure the system clock */
  SystemClock_Config();

  /* USER CODE BEGIN SysInit */
    int welcome_flag = 1;
    uint16_t *dac_samples_buffer = NULL;
  /* USER CODE END SysInit */

  /* Initialize all configured peripherals */
  MX_GPIO_Init();
  MX_DMA_Init();
  MX_I2C1_Init();
  MX_DAC_Init();
  MX_TIM1_Init();
  MX_TIM2_Init();
  MX_TIM3_Init();
  MX_TIM6_Init();
  MX_TIM8_Init();
  MX_ADC3_Init();
  /* USER CODE BEGIN 2 */
    //HAL_ADC_Start(&hadc3);
    HAL_TIM_Base_Start(&htim6); //Base de tiempo para la salida DAC
    HAL_TIM_Base_Start_IT(&htim3); //Base de tiempo para interrupciones de 100us
    HAL_TIM_PWM_Start(&htim2, TIM_CHANNEL_1); //Base de tiempo para la salida PWM
    HAL_TIM_Encoder_Start(&htim1, TIM_CHANNEL_ALL); //Inicializa el timer en modo encoder
    HAL_TIM_Encoder_Start(&htim8, TIM_CHANNEL_ALL); //Inicializa el timer en modo encoder
    welcome(); //mensaje de presentacion
  /* USER CODE END 2 */

  /* Infinite loop */
  /* USER CODE BEGIN WHILE */
    while (1)
    {

        /* Limpio el display luego de mostrar el mensaje de bienvenida por única vez*/
        if(counter>=WELCOMESCREEN_TIME)
        {
            if(welcome_flag==1)
            {
                cls_lcd();
            	welcome_flag = 0;
            }
        }
        /* Compruebo si un botón fue presionado*/
        button_check();

        /*Ejecuto el menú*/
        if(welcome_flag == 0)
        {
            dac_samples_buffer = menu(dac_samples_buffer);
        }
    }
    /* USER CODE END WHILE */

}

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
/* USER CODE BEGIN 4 */
void HAL_SYSTICK_Callback(void)
{
    counter++;
}

void welcome(void)
{
    init_lcd();
    cls_lcd();
    print_shifted((char*)"DIGITALES III", 1, 3);
    print_shifted((char*)"Generador", 2, 5);
    print_shifted((char*)"de", 3, 8);
    print_shifted((char*)"Funciones", 4, 5);
}

void button_check(void)
{
    static uint8_t state = IDLE;
    switch(state)
    {
    case IDLE:
        if(flag_callback_menu==ON)
        {
            state = CHECK;
            counter = 0;
            flag_callback_menu = 0;
        }
        break;
    case CHECK:
        if(counter >= DEBOUNCINGTIME)
        {
            if(pin_state == HAL_GPIO_ReadPin(GPIOD, button_callback))
            {
                if(pin_state == GPIO_PIN_SET)
                    state=PUSH;
                else
                    state=NPUSH;
            }
            else
                state = IDLE;
        }
        break;
    case PUSH:
        pressed_button = 1;
        button_action(button_callback);
        state = IDLE;
        break;
    case NPUSH:
        pressed_button = 0;
        state = IDLE;
        break;
    }
}


void HAL_GPIO_EXTI_Callback(uint16_t GPIO_Pin)
{
    button_callback = GPIO_Pin;
    pin_state = HAL_GPIO_ReadPin(GPIOD, button_callback);
    flag_callback_menu = 1;
}
/* USER CODE END 4 */
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


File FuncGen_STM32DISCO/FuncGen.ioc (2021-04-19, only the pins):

Mcu.UserName=STM32F407VGTx
PA1.Signal=ADCx_IN1
PA2.Signal=ADCx_IN2
PA3.Signal=ADCx_IN3
PA4.Signal=COMP_DAC1_group
PA5.Signal=S_TIM2_CH1_ETR
PA7.GPIO_Label=CD4051_A
PA7.Signal=GPIO_Output
PB6.Signal=I2C1_SCL
PB7.Signal=I2C1_SDA
PC6.Signal=S_TIM8_CH1
PC7.Signal=S_TIM8_CH2
PD0.GPIO_Label=LCD_D7
PD0.Signal=GPIO_Output
PD1.GPIO_Label=LCD_D6
PD1.Signal=GPIO_Output
PD10.GPIO_Label=BUTTON_DOWN
PD10.Signal=GPXTI10
PD12.GPIO_Label=LD4 [Green Led]
PD12.Signal=GPIO_Output
PD13.GPIO_Label=LD3 [Orange Led]
PD13.Signal=GPIO_Output
PD14.GPIO_Label=LD5 [Red Led]
PD14.Signal=GPIO_Output
PD15.GPIO_Label=LD6 [Blue Led]
PD15.Signal=GPIO_Output
PD2.GPIO_Label=LCD_D5
PD2.Signal=GPIO_Output
PD3.GPIO_Label=LCD_D4
PD3.Signal=GPIO_Output
PD4.GPIO_Label=LCD_RESET
PD4.Signal=GPIO_Output
PD5.GPIO_Label=LCD_ENABLE
PD5.Signal=GPIO_Output
PD8.GPIO_Label=BUTTON_UP
PD8.Signal=GPXTI8
PE11.Signal=S_TIM1_CH2
PE9.Signal=S_TIM1_CH1
PH0-OSC_IN.Signal=RCC_OSC_IN
PH1-OSC_OUT.Signal=RCC_OSC_OUT

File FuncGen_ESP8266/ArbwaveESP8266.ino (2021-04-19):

#include <FS.h>   // Include the SPIFFS library
#include <ESP8266WiFi.h>
#include <WiFiClient.h>
#include <ESP8266WebServer.h>
#include <ESP8266mDNS.h>
#include <WebSocketsServer.h>
#include <Wire.h>



ESP8266WebServer server(80);    // Create a webserver object that listens for HTTP request on port 80
WebSocketsServer webSocket(81);    // create a websocket server on port 81

String getContentType(String filename); // convert the file extension to the MIME type
bool handleFileRead(String path);       // send the right file to the client (if it exists)
void handleFileUpload();                // upload a new file to the SPIFFS
File fsUploadFile;              // a File object to temporarily store the received file

void setup()
  {
  //wdt_disable();
  pinMode(LED_BUILTIN, OUTPUT);
  digitalWrite(LED_BUILTIN, HIGH);
  Wire.begin();
  //Wire.setClock(400000);
  Serial.begin(115200);
 
  WiFi.mode(WIFI_STA);
  WiFi.begin("Noto", "LaNotoCas@14");
  Serial.println('\n');
  Serial.print("Connecting");

  while (WiFi.status() != WL_CONNECTED)
    {
    delay(500);
    Serial.print(".");
    }

  Serial.println();
  Serial.print("Connected to ");
  Serial.println(WiFi.SSID());
  Serial.print("Connected, IP address: ");
  Serial.println(WiFi.localIP());
  webSocket.begin();                          // start the websocket server
  webSocket.onEvent(webSocketEvent);          // if there's an incomming websocket message, go to function 'webSocketEvent'
  Serial.println("WebSocket server started.");

  if (!MDNS.begin("esp8266"))
    {
    Serial.println("Error setting up MDNS responder!");

    while (1)
      {
      delay(1000);
      }
    }

  Serial.println("mDNS responder started");
  SPIFFS.begin();                           // Start the SPI Flash Files System
  server.on("/", HTTP_GET, handleRoot);               // Call the 'handleRoot' function when a client requests URI "/"
  server.on("/LED", HTTP_POST, handleLED);  // Call the 'handleLED' function when a POST request is made to URI "/LED"
  server.on("/send", HTTP_POST, handleSend);
  server.on("/delete", HTTP_POST, handleDelete);
  server.onNotFound([]()                                // If the client requests any URI
    {
    if (!handleFileRead(server.uri()))                  // send it if it exists
      { server.send(404, "text/plain", "404: URi Not Found"); } // otherwise, respond with a 404 (Not Found) error
    });
  server.on("/upload", HTTP_GET, []()                   // if the client requests the upload page
    {
    if (!handleFileRead("/upload.html"))                // send it if it exists
      { server.send(404, "text/plain", "404: Not Found (Upload)"); } // otherwise, respond with a 404 (Not Found) error
    });
  server.on("/upload", HTTP_POST,                       // if the client posts to the upload page
            []()
    {
    server.send(200);
    },                          // Send status 200 (OK) to tell the client we are ready to receive
  handleFileUpload                                    // Receive and save the file
           );
  // Start TCP (HTTP) server
  server.begin();
  Serial.println("TCP server started");
  // Add service to MDNS-SD
  MDNS.addService("http", "tcp", 80);
  }

void loop()
  {
  webSocket.loop();                           // constantly check for websocket events
  MDNS.update();
  server.handleClient();                    // Listen for HTTP requests from clients
  }

void handleRoot()
  {
  //server.send(200, "text/plain", "Hello world!");   // Send HTTP status 200 (Ok) and send some text to the browser/client
  //server.send(200, "text/html", s);
  File file = SPIFFS.open("/pagina_principal.html", "r");                 // Open it
  size_t sent = server.streamFile(file, "text/html"); // And send it to the client
  //file.print("<h2 style=text-align: center;><span style=color: #ff0000; data-darkreader-inline-color=><em><strong>Ya es hora de merendar!</strong></em></span></h2>");
  file.close();
  }

void handleLED()                            // If a POST request is made to URI /LED
  {
  digitalWrite(LED_BUILTIN, !digitalRead(LED_BUILTIN));     // Change the state of the LED
  FSInfo fs_info;
  Dir dir = SPIFFS.openDir("/");

  if (SPIFFS.info(fs_info))
    {
    Serial.printf("Total Bytes %s \n",fs_info.totalBytes);
    Serial.printf("Used Bytes %s \n",fs_info.usedBytes);
    Serial.printf("Block Size %s \n",fs_info.blockSize);
    Serial.printf("Page Size %s \n",fs_info.pageSize);
    Serial.printf("Max Open Fles %s \n",fs_info.maxOpenFiles);
    Serial.printf("Max Path Lenght %s \n",fs_info.maxPathLength);

    while (dir.next())
      {
      Serial.println(dir.fileName());
      }
    }

  server.sendHeader("Location", "/");       // Add a header to respond with a new location for the browser to go to the home page again
  server.send(303);                         // Send it back to the browser with an HTTP status 303 (See Other) to redirect
  }


String getContentType(String filename)   // convert the file extension to the MIME type
  {
  if (filename.endsWith(".html")) { return "text/html"; }

  else
    if (filename.endsWith(".css")) { return "text/css"; }

    else
      if (filename.endsWith(".csv")) { return "text/csv"; }

      else
        if (filename.endsWith(".js")) { return "application/javascript"; }

        else
          if (filename.endsWith(".png")) { return "image/png"; }

          else
            if (filename.endsWith(".pdf")) { return "application/pdf"; }

            else
              if (filename.endsWith(".doc")) { return "application/msword"; }

              else
                if (filename.endsWith(".txt")) { return "text/txt"; }

                else
                  if (filename.endsWith(".ico")) { return "image/x-icon"; }

  return "text/plain";
  }

bool handleFileRead(String path)   // send the right file to the client (if it exists)
  {
  Serial.println("handleFileRead: " + path);

  if (path.endsWith("/")) { path += "index.html"; }         // If a folder is requested, send the index file

  String contentType = getContentType(path);            // Get the MIME type

  if (SPIFFS.exists(path))                              // If the file exists
    {
    File file = SPIFFS.open(path, "r");                 // Open it
    size_t sent = server.streamFile(file, contentType); // And send it to the client
    file.close();                                       // Then close the file again
    return true;
    }

  Serial.println("\tFile Not Found");
  return false;                                         // If the file doesn't exist, return false
  }
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

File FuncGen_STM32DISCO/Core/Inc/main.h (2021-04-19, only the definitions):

#define CD4051_A_Pin GPIO_PIN_7
#define CD4051_A_GPIO_Port GPIOA
#define BUTTON_UP_Pin GPIO_PIN_8
#define BUTTON_UP_GPIO_Port GPIOD
#define BUTTON_UP_EXTI_IRQn EXTI9_5_IRQn
#define BUTTON_DOWN_Pin GPIO_PIN_10
#define BUTTON_DOWN_GPIO_Port GPIOD
#define BUTTON_DOWN_EXTI_IRQn EXTI15_10_IRQn
#define LD4_Pin GPIO_PIN_12
#define LD4_GPIO_Port GPIOD
#define LD3_Pin GPIO_PIN_13
#define LD3_GPIO_Port GPIOD
#define LD5_Pin GPIO_PIN_14
#define LD5_GPIO_Port GPIOD
#define LD6_Pin GPIO_PIN_15
#define LD6_GPIO_Port GPIOD
#define LCD_D7_Pin GPIO_PIN_0
#define LCD_D7_GPIO_Port GPIOD
#define LCD_D6_Pin GPIO_PIN_1
#define LCD_D6_GPIO_Port GPIOD
#define LCD_D5_Pin GPIO_PIN_2
#define LCD_D5_GPIO_Port GPIOD
#define LCD_D4_Pin GPIO_PIN_3
#define LCD_D4_GPIO_Port GPIOD
#define LCD_RESET_Pin GPIO_PIN_4
#define LCD_RESET_GPIO_Port GPIOD
#define LCD_ENABLE_Pin GPIO_PIN_5
#define LCD_ENABLE_GPIO_Port GPIOD

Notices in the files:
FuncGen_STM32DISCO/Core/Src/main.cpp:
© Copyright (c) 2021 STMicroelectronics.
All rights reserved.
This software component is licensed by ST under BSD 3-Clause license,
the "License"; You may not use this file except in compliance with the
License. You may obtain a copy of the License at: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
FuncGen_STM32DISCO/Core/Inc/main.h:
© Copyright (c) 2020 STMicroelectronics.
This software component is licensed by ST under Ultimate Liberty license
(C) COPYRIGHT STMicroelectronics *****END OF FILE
